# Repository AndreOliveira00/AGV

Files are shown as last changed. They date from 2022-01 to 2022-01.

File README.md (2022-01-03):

# AGV
 Automated Guided Vehicle Controlled by Atmega328P

Este repositório contém o relatório do projeto desenvolvido na Licenciatura de Engenharia Eletrotécnica e de Computadores na Unidade curricular LABSI. 
Imagens ilustrativas da PCB final e o desenvolvimento associado.

<b>OBJETIVOS DO PROJETO:</b>
<ul>
<li>Controlo do movimento do veículo, estabelecendo velocidade e sentido de rotação de 2 motores DC;</li>
<li>Processamento dos dados obtidos por um sensor de proximidade ultrassónico de forma a definir o movimento do carro;</li>
<li>Implementação do projeto segundo a orientação do microcontrolador ATMega328P;</li>
<li>Desenvolvimento de toda a programação C assim como desenho das PCB necessárias á execução do projeto;</li>
</ul>

Para outros esclarecimentos contacte pelo email 1181045@isep.ipp.pt.

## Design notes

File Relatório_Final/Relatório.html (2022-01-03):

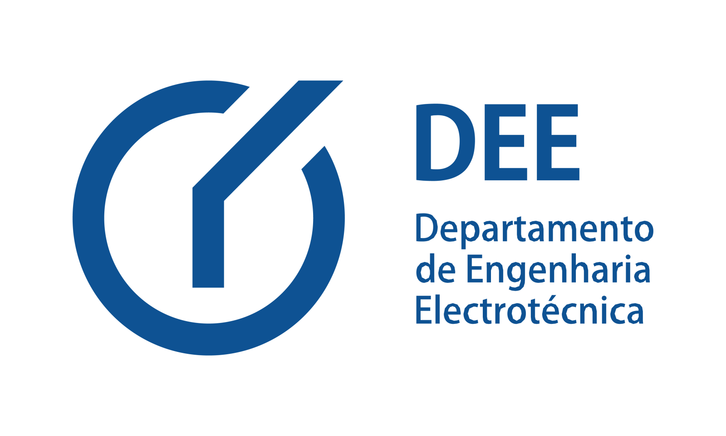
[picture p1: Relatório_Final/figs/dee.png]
| | Veículo autónomo - AGV | | | | | | |  LABSIS 2020/2021
Autores:
| André Oliveira (Nº 1181045) | | | | | 1181045@isep.ipp.pt
| Rodrigo Teixeira (Nº 1160843) | | | | | 1160843@isep.ipp.pt
Introdução | | | Arquitetura | Hardware | Software | | Resultados | Conclusões | | Referências
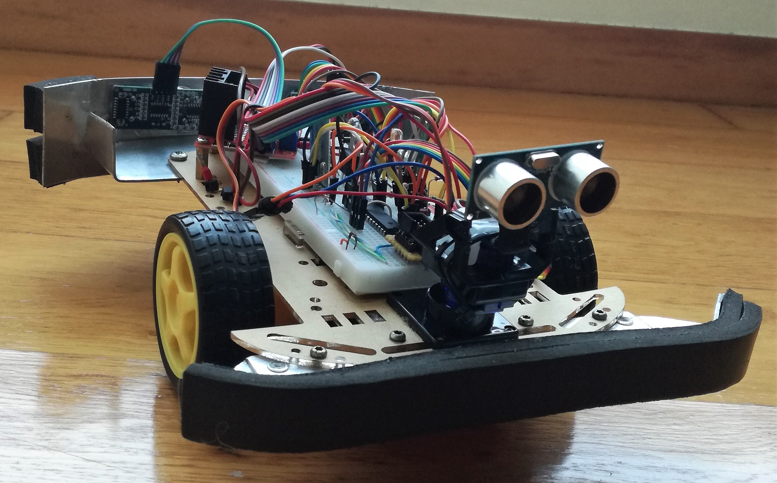
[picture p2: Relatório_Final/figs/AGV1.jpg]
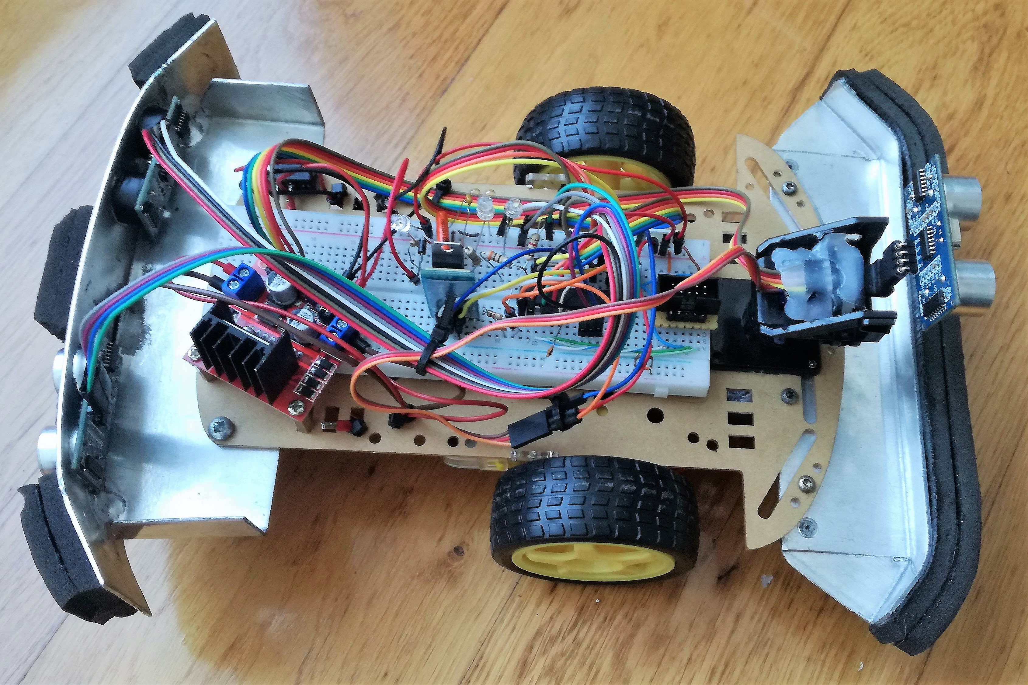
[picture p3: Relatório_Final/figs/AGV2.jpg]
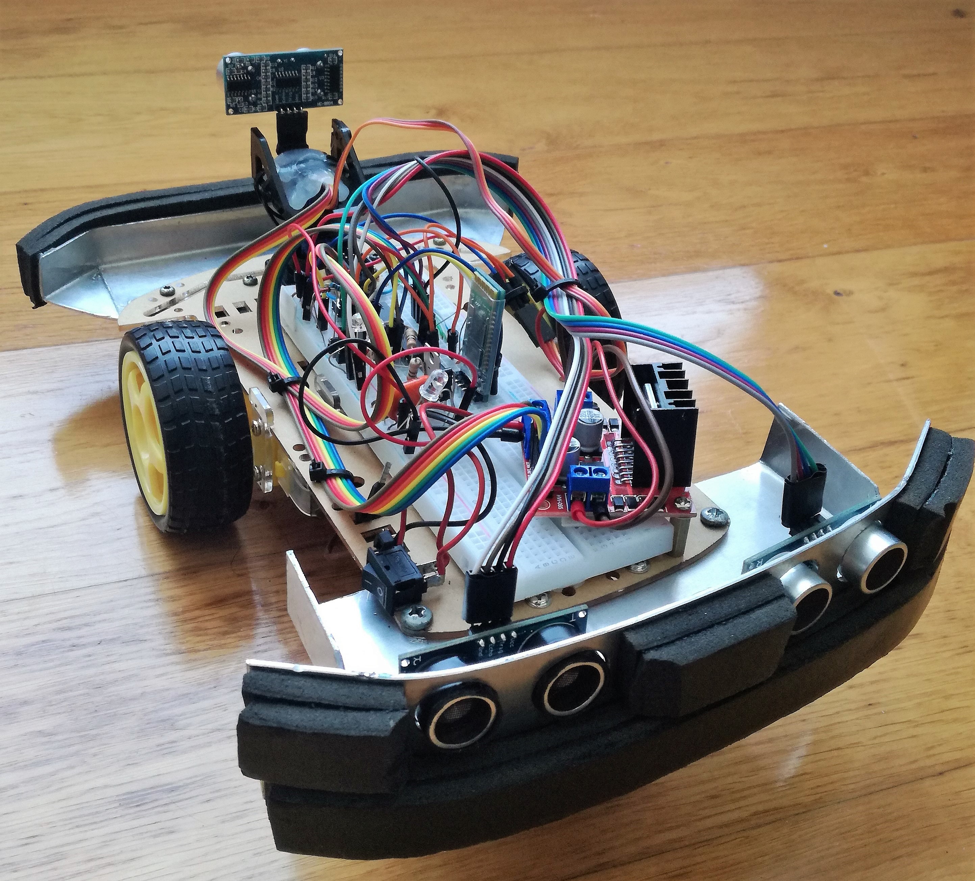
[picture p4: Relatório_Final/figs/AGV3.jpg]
  
Introdução | | | | | | | | | | | Início

No âmbito da Unidade Curricular Laboratório de Sistemas, foi proposta a conceção de um projeto com o respetivo protótipo funcional que recrutasse conhecimentos adquiridos ao longo do curso. Neste sentido, comprometemos-mos no desenvolvimento de um veículo autónomo, explorando posteriormente o seu controlo remotamente.
O presente relatório expõe os aspetos mais pertinentes que foram tidos em consideração durante o desenvolvimento do protótipo, destacando as principais dificuldades e realçando os conhecimentos adquiridos.

Objetivos

O compromisso para o desenvolvimento de um AGV passou pela estipulação das metas a serem atingidas. Com foco sempre na elaboração de um projeto eficaz e também económico foram enumerados os seguintes objetivos:

Controlo do movimento do veículo, estabelecendo velocidade e sentido de rotação de 2 motores DC;

Processamento dos dados obtidos por um sensor de proximidade ultrassónico de forma a definir o movimento do carro;

Implementação do projeto segundo a orientação do microcontrolador ATMega328P;

Desenvolvimento de toda a programação C assim como desenho das PCB necessárias á execução do projeto;

Modulação de um sistema económico e de carácter didático;

Estado da Arte

Com o desenvolvimento das tecnologias focadas no ramo de veículos autónomos e o aumento da capacidade computacional, foram nos apresentados os primeiros "robôs móveis" industriais. Esta conceção conjuga num só dispositivo de automação a capacidade de manipulação e manuseamento dos robôs e a mobilidade de um veículo autónomo. Neste campo destacam-se os AGV (Automatic Guided Vehicle), LGV (Laser Guided Vehicles), SGV (Self-Guided Vehicles) e AGC (Automated Guided Carts) com enorme potêncial no domínio industrial ou distribuição[1].

Um AGV é um veículo móvel autoguiado utilizado em ambientes que requerem transporte de produtos na produção e em armazéns. São programados com rotas definidas de recolha e entrega de materiais dentro de instalações de manufatura e de distribuição[2].

A sua flexibilidade permite a instalação em fábricas com reduzidas alterações na estrutura do shop floor. Geram um aumento da eficiência na produção dado redução dos recursos humanos necessários no desenvolvimento de trabalho repetitivo e permitindo uma cadência de ritmo de operação fixa. Os mesmos requerem pouca supervisão[3].

Alguns métodos de navegação como o Sistema Filoguiado consiste na definição do percurso do AGV por intermédio de condutores elétricos embutidos no chão. Estes condutores geram um campo magnético devido à corrente elétrica sinusoidal que por eles atravessam, seguidamente detetada por uma antena colocada no AGV conforme ilustrado na figura 1.(a) [4]. Um sistema pouco flexível e que implica a alteração do shop floor da fábrica[2].

Uma outra alternativa seria a substituição desse fio condutor por uma Fita Magnética ou Linhas Pintadas distintas na tonalidade relativamente ao resto do chão. A principal vantagem reside na flexibilidade com que se instala uma nova rota para o dispositivo conforme ilustrado na figura 1.(b)[4]. Porém o desgaste das fitas poderão interromper o trajeto do AGC (veículo apropriado)[2].

O sistema de Trilateração e Triangulação Laser apresenta-se como a forma de navegação mais segura que garante maior precisão do veículo através do mapeamento na memoria do mesmo. O AGV usa um sistema de lasers rotativos que permitem captar postes ou faróis refletores devidamente alocados conforme ilustrado na figura 1.(c) [4]. O resultado, o dispositivo não se perde sendo necessário detetar 3 destes faróis para ser capaz de obter a sua localização[2].

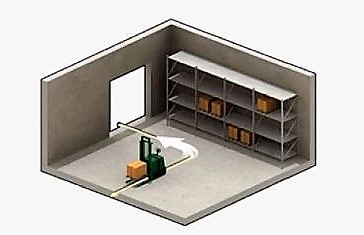
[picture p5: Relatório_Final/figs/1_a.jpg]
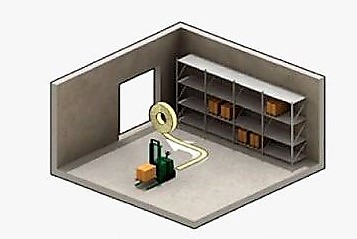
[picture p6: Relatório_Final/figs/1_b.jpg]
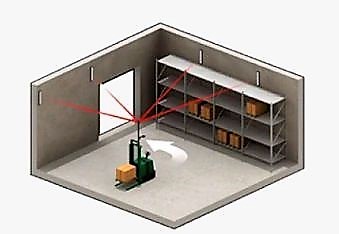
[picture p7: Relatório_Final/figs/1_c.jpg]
  

(a) Navegação por Sistema Filoguiado (b) Navegaço por uso de Fita Magnética/Pintada (c) Navegação por Sistema Triangulação Laser

Figura 1 - Métodos de Navegação

A orientação por GPS (Global positioning system) paralelamente com um sensor de bússola não apresentam resultados satisfatórios no interior de um edifício devido a bloqueios causados pelo mesmo, porém esta hipótese pode ver a ser desenvolvida com o auxílio de uma plataforma móvel, como um dispositivo Android, tendo apenas como pré requisitos a inclusão destes dois sensores[5]. O mesmo sistema seria benéfico na necessidade de transporte de mercadoria para um terreno de um hectare, sem constrições algumas, o sistema de GPS seria mais que suficiente dado a sua precisão rondar os 20 metros[6].

A implementação a partir de um sonar rotativo capaz de realizar um varrimento restrito de forma a obter um mapeamento dos obstáculos em frente do mesmo afasta-se um pouco da prática industrial, mas segue uma filosofia idêntica, automatização de um veículo. Para aplicações de pequena dimensão pode ser utilizado um servomotor capaz de controlar a rotação de 180° do sonar. Abordar este projeto com apenas um sonar implica um consumo de mais tempo no varrimento de todo o espaço por ele abrangido se quisermos manter alguma fiabilidade no sistema [7].

Uma implementação com recurso a 4 rodas teria uma estrutura idêntica à de um carro comum, ou seja, as rodas da frente teriam o controlo da direção e tração. Pretende-se apenas como requisito haver um sistema dotado destas características [2]. Relativamente à implementação com 2 rodas, esta pode ser encontrada em 2 versões comuns. Configuração diferencial, um eixo dianteiro com 2 motores de tração, sendo a direção controlada pelo sentido destas (a título de exemplo, uma movimentação para o lado direito requeria no motor esquerdo rotação da roda para a frente enquanto a direita faria o movimento contrário e vice-versa). Usual é também a configuração com 2 rodas de tração e direção, uma à frente e outra atrás com movimento de 360° , contendo duas rodas a meio, lado a lado, de apoio[2] , conforme ilustrado na figura 2.(a)[3].

Uma configuração unidirecional, composta por uma roda dianteira de tração e direção que roda sobre si própria. É chamado de controlo de tração triciclo visto incluir um eixo traseiro composto por duas rodas fixas, conforme ilustrado na figura 2.(b)[3]. Adicionalmente o controlo de direção também pode ser feito através de 3 (ou mais) rodas fixas na direção, desfasadas de 120° conforme ilustrado na figura 2.(c)[8]. Tem por desvantagem a necessidade um controlo mais complexo[3].

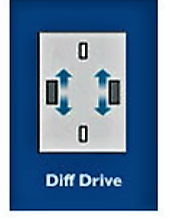
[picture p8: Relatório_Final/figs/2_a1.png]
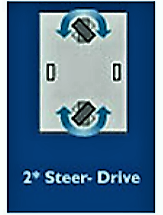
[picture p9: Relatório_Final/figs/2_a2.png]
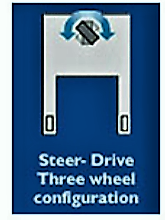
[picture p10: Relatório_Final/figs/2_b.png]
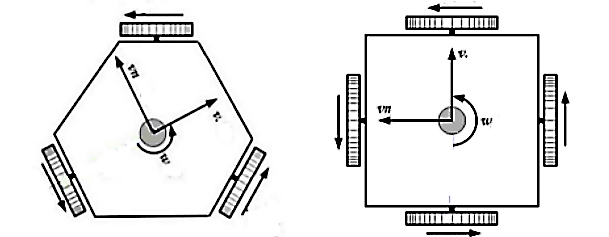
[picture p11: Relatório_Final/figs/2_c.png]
   

(a) Configurações diferenciais (b) Configuração unidirecional (c) Configurações omnidirecionais

Figura 2 - Configurações da locomoção dos AGV's

Sincronizado com o projeto e com o intuito de garantir a integridade do AGV no meio envolvente podemos equipá-lo com diversos equipamentos de segurança. A deteção de colisões através de sensores de obstáculos capaz de os detetarem calculando a distância entre este e o equipamento. Obstáculos mais baixos podem ser protegidos por uso de para-choques que quando acionados garantem a paragem instantânea do AGV. O uso de sinal de Áudio/Visual para alertar, por exemplo outros equipamentos ou mesmo trabalhadores da sua presença. Ou até segundo um controlo manual composto por botões de emergência que obrigam a paragem brusca do AGV.

A troca de informação entre AGV's sem a intervenção do humano proveniente do surgimento da IoT (Internet of Things) melhorou a monitorização do tráfego dos veículos. Estas comunicações podem ser realizadas com uso de transmissão rádio sendo necessário calcular o número de antenas necessárias bem como a sua colocação. Poderá ocorrer interferências criadas por sinais emitidos a pouca distância. Outra abordagem seria o uso da comunicação por infravermelhos tendo como desvantagem o facto de ser point to point, provocando interrupções do movimento do veículo aquando da transmissão de informação. Esta metodologia torna-se mais adequado para sistemas de baixa velocidade e menos ambiciosos. A comunicação por fio guia responsável por orientar o AGV evitando a ocorrência de "zonas mortas", uma das desvantagem da comunicação rádio. Na comunicação por circuitos de indução são criados circuitos dotados da criação de campo magnético à sua volta, responsáveis por transmitir comandos à antena dos AGV's e passada ao PLC (Programmable Logic Controller), que age em conformidade com o que lhe foi transmitido. Por último, a comunicação por Wi-Fi, sistema mais comum devido à sua flexibilidade e escalabilidade[9][2].

A forma como é realizada o carregamento do AGV pode definir a complexidade dos sistemas instalados assim como o número de equipamentos necessários. A troca manual que implica a imobilização do veículo entre 5 a 10 minutos. A automática recorrendo a uma estação própria para esse efeito. Carregamento de oportunidade, ou seja, utilizar o tempo de paragem do AGV para reabastecer as suas baterias. Carregamento automático, realiza as suas funções até determinada percentagem de energia. O carregamento fast charging, para carregamentos breves e frequentes das baterias. E o carregamento por indução, devido ao campo magnético gerado numa bobina que obriga a colocação de uma outra no veículo (a distâncias de 13 cm apresenta taxas de eficiência bastante elevadas, cerca de 97.4 %)[6].
Arquitetura | | | | | | | | | | | Início

Na figura 3, podemos observar a tradução das ideais estipuladas em algo físico. Ao diagrama de blocos do sistema mínimo, realizado anteriormente e presente também neste projeto, foi acrescentado os módulos necessários para a realização do mesmo.

Para a implementação de um AGV com os elementos mencionados necessitamos, principalmente de, mobilidade e autonomia. Estes dois fatores vão ser garantidos através da Ponte H L298N, à qual foram agregados dois motores DC, e pelas leituras efetuadas pelo Sonar HC-SR04 que por sua vez vai detetar obstáculos em várias direções com a ajuda de um Servo Motor SG90. Não abstante, são precias quatro baterias ICR18650, que na totalidade perfazem 14.8 V e 2200 mAh necessários para alimentar o veículo. Contudo, como o ATMega328P e a maioria dos módulos são alimentados apenas com 5 V contínuos, foi usado um Regulador de Tensão LM7805 que permite obter uma tensão de saída constante juntamente com um circuito de filtragem.

Adicionalmente, o grupo pensou que seria interessante o controlo remoto do AGV, para tal é necessário estabelecer comunicação entre o mesmo e uma aplicação de controlo, neste caso, via Bluetooth. Foi implementado um Módulo Bluetooth HC-05, com a finalidade mencionada anteriormente, a interface de controlo utilizada foi a aplicação Bluetooth Electronics. Com abertura para melhorias, foram adicionados mais dois Sonares HC-SR04 na parte traseira do veículo, de forma a evitar também qualquer objeto na marcha à retaguarda.

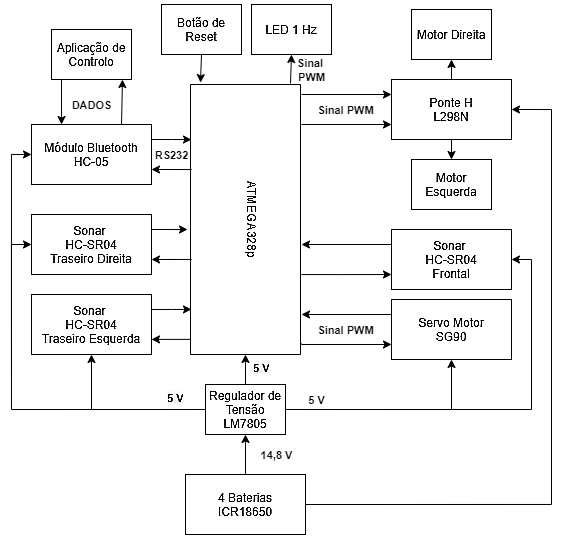
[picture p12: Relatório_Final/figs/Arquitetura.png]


Figura 3 - Arquitetura do AGV
Hardware | | | | | | | | | | | Início

ATMega328P

De modo a dar continuação ao projeto mínimo, sendo a implementação deste necessária neste trabalho, o grupo optou por usufruir do mesmo microcontrolador ATMega328P (https://datasheetspdf.com/pdf-file/1057332/ATMEL/ATmega328P/1). Este tipo de microcontroladores têm uma variante SMD ( Surface Mount ) e THT ( Through Hole Technology ), sendo a primeira variante de um tamanho muito mais reduzido e ideal para produção em grande escala, não sendo o caso, a tecnologia THT facilita a implementação, por exemplo, num PCB ou breadboard [10].

Este microcontrolador de 8 bits pode ser encontrado nas placas Arduino, sendo um dos mais populares do mercado. Dispõem de 28 pinos e tem 3 portas para uso, D, C e B. Para além do ATMega328P estava disponível o ATMega168, a principal diferença significativa entre os mesmo é a quantidade de memória programável, onde o escolhido apresenta o dobro[11]. O pinout do circuito pode ser visualizado na figura 4.

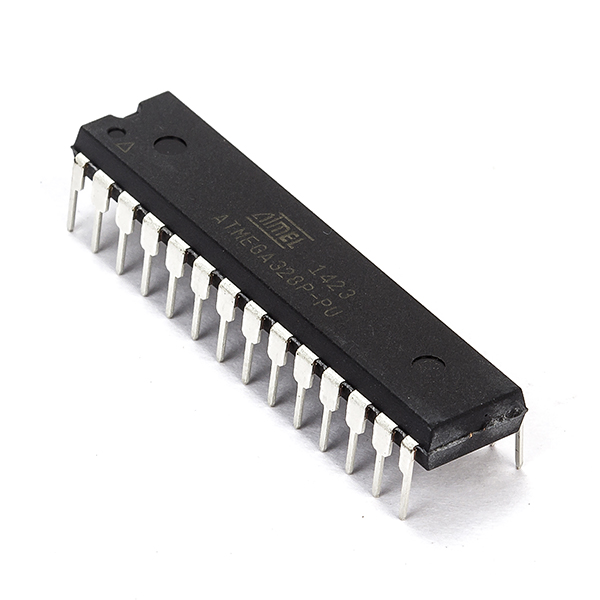
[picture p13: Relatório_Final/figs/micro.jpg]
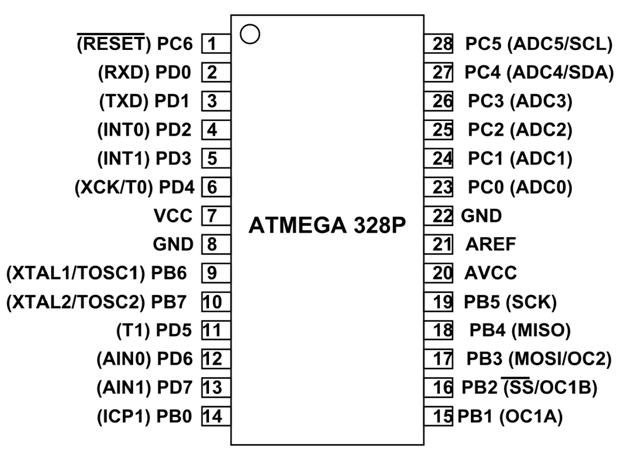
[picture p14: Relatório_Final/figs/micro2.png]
 

(a) ATMega328P (b) Pinout

Figura 4 - ATMega328P

Circuito de alimentação

a. Regulador de Tensão LM7805

O sistema de alimentação é uma das partes mais importantes do projeto, uma vez que sem este é impossível o correto funcionamento do AGV. Logo, visando também os movimentos autónomos do veículo a opção mais rentável seriam baterias, tendo em consideração também a portabilidade do mesmo. O regulador de tensão LM7805 (https://www.mouser.com/datasheet/2/149/LM7805-1010961.pdf) tem como principal função manter a tensão na sua saída constante. O circuito de regulação deve ser acompanhado de díodos e condensadores, criando assim um circuito de proteção contra eventuais descuidos e potenciais curto-circuitos[12].

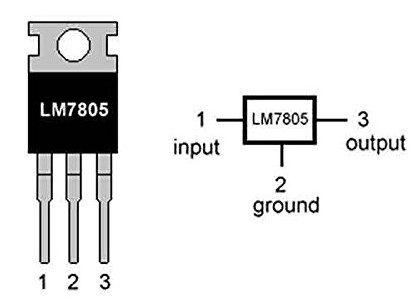
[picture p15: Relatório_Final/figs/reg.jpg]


Figura 5 - LM7805

A tensão de entrada pode variar entre os 7 V e 25 V, e a corrente máxima de 1 A ou 1,5 A, sendo o regulador selecionado de 1 A. É preciso ter em conta que este regulador pode libertar até 15 W de potência, sendo aconselhável o uso de um dissipador. O mesmo deve ser aplicado na traseira do regulador. De forma a proteger o veículo contra possíveis inversões de polaridade foi colocado um díodo diretamente polarizado na entrada, e para suavizar a tensão de saída e diminuir ruídos eletromagnéticos foram usados dois condensadores de desacoplamento, um na entrada de 0,33 µF e 0,1 µF na saída, reduzindo assim o efeito de ripple[13].

b. Baterias

As baterias de lítio ICR18650 de 3.7 V e 2200mAh são uma excelente escolha para este projeto, relativamente a baterias de outros materiais como níquel e chumbo, estas são mais leves e não sofrem do efeito de memória, características que são necessárias ter em mente ao dimensionar um AGV que visa a mobilidade.

As baterias selecionadas foram ligadas em série permitindo um acumular de 14.8 V e 2200 mAh quando devidamente carregadas. Dado a utilidade referida e a procura da reutilização de material, pudemos encontrá-las em baterias antigas de notebooks (com algum desgaste, mas estáveis o suficiente para efeito de desenvolvimento).

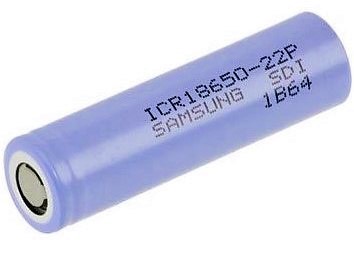
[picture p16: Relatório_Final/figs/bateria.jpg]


Figura 6 - Bateria ICR18650

Foram utilizadas 4 baterias ICR18650 sendo importante garantir que as baterias são todas do mesmo material, erros deste tipo podem levar ao mau desempenho do AGV ou até mesmo danificar-lo, podendo até se verificar sobreaquecimento ou fugas de corrente.

c. Circuito de proteção

Como mencionado anteriormente, o circuito de proteção permite evitar possíveis descuidos, como também eventuais curto-circuitos. Este detêm de dois díodos colocados em paralelo com a alimentação do microcontrolador, o Díodo Zener 5.1 V (https://www.jameco.com/Jameco/Products/ProdDS/36097VIS.pdf) atua como limitador de uma tensão teórica de 5.1V (limite de alimentação do ATMega328P de 5.5V) no caso de rutura do circuito de regulação.

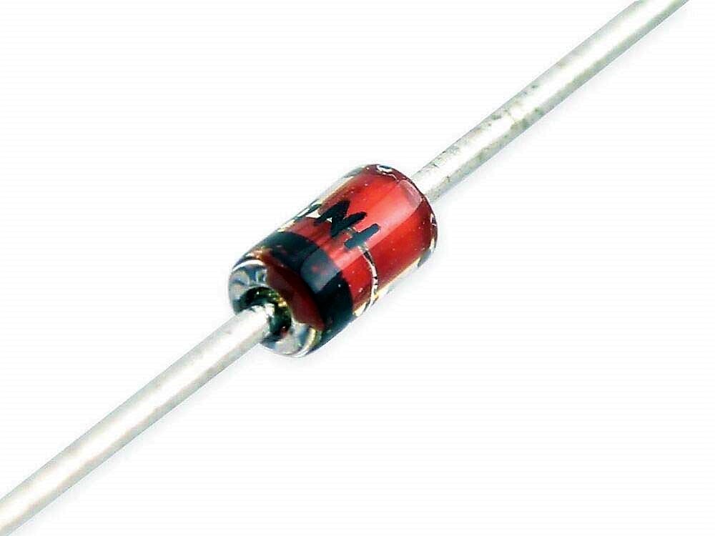
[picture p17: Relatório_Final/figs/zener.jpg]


Figura 7 - Díodo Zener 5.1 V

Paralelamente foi colocado um TVS (https://m.littelfuse.com/~/media/electronics/product_catalogs/littelfuse_tvs_diode_catalog.pdf.pdf) (Transiente Voltage Suppressor) e como o nome indica são utilizados em circuitos sensíveis onde ocorra uma repentina comutação de tensão num curto intervalo de tempo. Este componente é capaz de limitar a 9.2 V teóricos tensões de overshoot na passagem de 0 V para 5 V e dissipar esse excesso de potência na forma de calor.

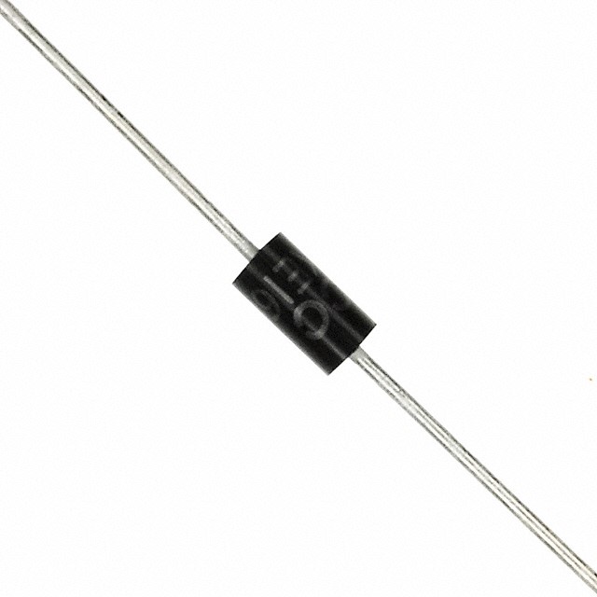
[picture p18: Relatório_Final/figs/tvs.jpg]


Figura 8 - TVS SMAJ5.0A

Módulo HC-05

No âmbito da comunicação entre aparelhos e transmissão de dados, o padrão global Bluetooth permite, em curtas distâncias e com baixo consumo de energia, uma ligação e tempo de resposta adequados para os AGV’s. Funciona através de limite de proximidade onde a comunicação é estabelecida através de frequência rádio aberta e permite transmissão como receção de dados sem necessitar de qualquer ligação física, sendo esta última abordagem extremamente adequada nestes projetos[14].

O módulo Bluetooth HC-05 (https://components101.com/sites/default/files/component_datasheet/HC-05%20Datasheet.pdf) permite implementar a ligação remota através de Serial Port Protocol seguindo o padrão RS232 entre este e o ATMega328P, podendo ser configurado como Master (consegue criar ligações com outros dispositivos) ou Slave (apenas consegue aceitar ligações criadas), sendo a segunda configuração implementada de origem pelo fabricante. Também existe o modo Loopback, fortemente utilizado para efeitos de teste, permite receber informações do Master e retorná-las seguidamente[15].

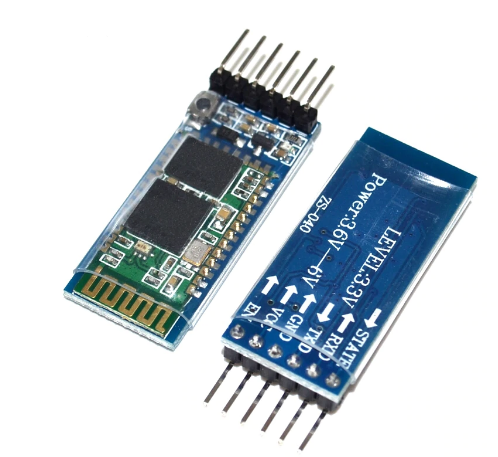
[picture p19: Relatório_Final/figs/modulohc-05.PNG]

Figura 9 - Módulo HC-05

Sonar HC-SR04

O sonar é de grande utilidade para um veículo autónomo. Composto por um transmissor e recetor, permite calcular a distância de a um determinado objeto. Transmite um impulso de som, chamado muitas vezes de ping, e após a emissão espera pela receção das reflexões/ecos do impulso criadas por eventuais obstáculos. É através deste modo que o recetor consegue calcular a distância após algum processamento de sinal[16].
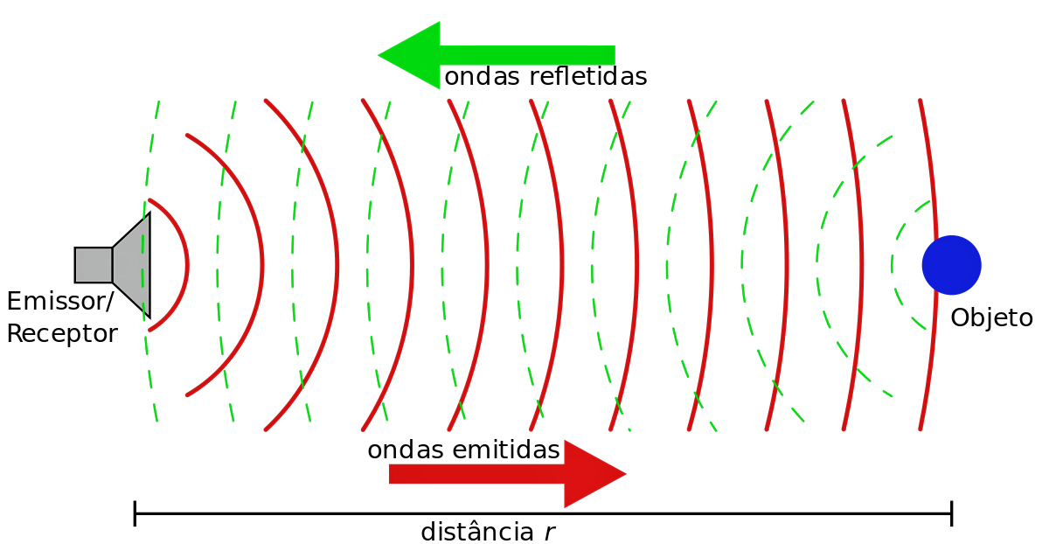
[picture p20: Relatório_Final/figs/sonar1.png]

Figura 10 - Funcionamento do Sonar

Existem variadíssimos sonares e imensos tipos de aplicação, no caso do AGV é de grande interesse ter o transmissor e recetor no mesmo local a realizar um movimento rotacional de forma a cobrir a maior área possível, pois permite ao veículo evitar obstáculos, e traçar melhor a sua rota. Este tipo de aplicação é designado de operação monoestática[17].

Um aspeto fulcral nos AGV’s é a sua mobilidade. Ou seja, têm de ser capazes de efetuar as manobras necessárias para se desviar de objetos, movendo-se por caminhos de difícil acesso ou evitar colisões com outros dispositivos idênticos. Para isto acontecer, a dimensão, peso e adaptabilidade do AGV são apenas alguns fatores a ter em consideração no momento de projeção deste tipo de projeto[16].

O sonar ultrasónico HC-SR04 permite atender às necessidades do projeto, tem capacidade de medir distâncias de 2 cm até 4 m com uma precisão de 4 mm. A velocidade do sinal emitida corresponde à velocidade do som (343 m/s), e também é uma opção ideal para microcontroladores devido à sua baixa corrente de operação (2mA) e alimentação de 5 V.
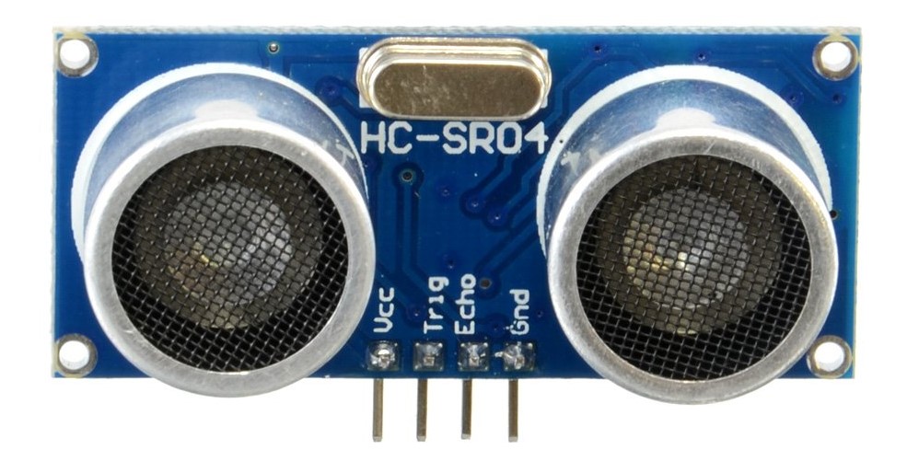
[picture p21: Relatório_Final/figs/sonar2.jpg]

Figura 11 - Sonar HC-SR04

Ponte H

A Ponte H é utilizada para controlar os motores DC em diversos campos da robótica, tais como locomoção de robôs, braços mecânicos e etc. Este tipo de circuito é de extrema importância ao trabalhar com microcontroladores, isto porque, os motores DC são cargas indutivas que requerem normalmente correntes superiores às que o microcontrolador consegue fornecer.

Posto isto, ao ligar diretamente o motor a uma das suas saídas poderíamos danificar o mesmo. Este problema poderia ser solucionado com um transístor, porém, não seria possível inverter a polaridade do motor[18]. Visando assim o tópico da adaptabilidade do AGV, a Ponte H acaba por ser uma elegante solução para este problema, pois é capaz de inverter a polaridade dos motores e também de regularas suas velocidades atrás da aplicação de um sinal PWM nos pinos de controlo[18].
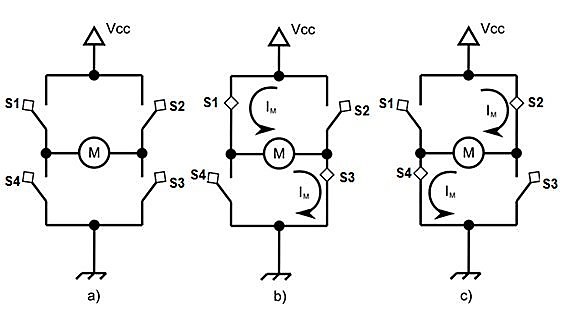
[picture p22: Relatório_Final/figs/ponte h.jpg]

(a) Desligado (b) Sentido Normal (c) Sentido Contrário

Figura 12 - Ponte H

Para melhor dimensionamento do AGV, é necessário manter os tópicos abordados anteriormente em mente, portanto tornar os circuitos o mais compacto possível é uma obrigação. O circuito integrado L298N ocupa menor espaço e é de baixa complexidade, para além disso permite o controle de dois motores. Para além destas vantagens, o mesmo responde a sinais PWN, tornando assim possível regular as tensões de saída e desta forma regular a velocidade dos motores[19].

Figura 13 - Módulo Ponte H com CI L298N

Para usufruir do sinal PWN e movimentar o AGV com velocidade regulável são usados dois Motores TT de 3 a 6 V com duas rodas acopladas. De dimensões reduzidas estes são uma aposta perfeita para pequenos projetos como este, atingem uma velocidade de 200 +/- 10 % rpm sem carga com uma corrente a rondar os 160 mA e alimentados a 6 V DC. Já com 3 V DC, sem carga acoplada, podemos contar com um débido te corrente de cerca de 150 mA e uma velocidade de 90 +/- 10 % rmp [20].
Já que a tensão de referência ronda os 14.8 V, via software decidimos limitar a 6 V DC aos motores. Esta ação é possível limitando o valor de OCR0A e OCR0B, no caso, uma variável global que define a velocidade aplicada em ambos. Considerando a tensão a aplicar aos motores varia linearmente com o duty cycle da onda PWM gerada pelo TIMER0, podemos conseguir o referido limitando a um valor de 103. Ou seja, (103/255) * 14.8 = 5.978 V.

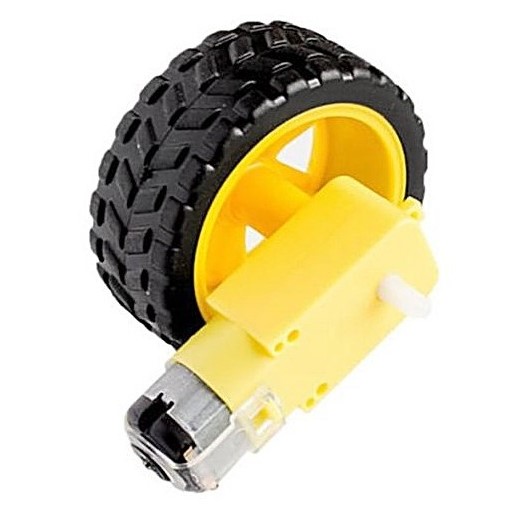
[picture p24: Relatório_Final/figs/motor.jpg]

Figura 14 - Motor DC com roda

Para além dos dois motores que efetuam o deslocamento do AGV é utilizado um terceiro, um servo motor SG90. Este é responsável pela rotação do sonar frontal sendo capaz de rodar 60º em 0.12 segundos[21]. Infelizmente o mesmo não foi verificado durante o projeto, pelo que foi necessário definir um “delay mecânico” durante a rotação do sonar de forma a não criar distúrbios maiores nas leituras realizadas pelo mesmo.

Conta com uma tensão operacional de 5 V e um consumo de 220 mA. Alimentado a 4.8 V regista um torque de 1.2 kg sem qualquer carga, suficiente para deslocar o sonar. Opera a uma frequência de 50 Hz, pelo que o PWM que o controla deve ter um período de 20 ms dos quais um duty cycle a 5 % (On-Time 1 ms) coloca o servo motor a -90 graus e um duty cycle a 10 % (On-Time 2 ms) coloca o servo motor a +90 graus, segundo as considerações feitas na Tabela 3 [21].


Figura 15 - Servo SG90

Roda livre giratória

A roda proveniente do kit adquirido para montar a estrutura do AGV apresenta algum atrito quando este pretende seguir em frente tendo previamente iniciado uma rotação. Esta oposição ao movimento condiciona a qualidade de deslocamento do veículo. Para correção do sucedido o grupo optou por adquirir uma roda que apresentasse melhor comportamento. A roda selecionada encontra-se na figura 16. De frisar que esta roda ainda podia ser substituída por uma roda livre esférica, não sendo necessário o sistema deslocar-se conforme o movimento.



Figura 16 - Roda livre giratória adotada

Para-choques

Seguindo as estruturas existentes no mercado relativamente a AGV’s industriais e de forma a garantir a integridade deste no meio envolvente foi desenvolvido dois para-choques com capacidade de aguentar embates em objetos segundo a altura do chassi e na parte de trás de forma a segurar os dois sonares. A estrutura é feita de alumínio pesando cerca de 250 g o que corresponde a um acréscimo de 45.5 % da massa original do AGV e 31.3 % da massa total. As proteções são rebitadas nas laterais e dobradas permitindo uma maior abrangência do veículo na altura do embate.

Programador

O programador USBASP (https://eecs.oregonstate.edu/education/docs/ece375/USBASP-UG.pdf) (USB AVR Serial Programmer) com conexão USB integrada permitiu realizar comunicação série entre o microcontrolador e o computador sendo apenas necessário estabelecer as devidas ligações e configurações a esse efeito, pudendo então enviar o ficheiro .hex, portador do código desenvolvido para controlo do AGV.

Constituído por uma ATMega8 ou ATMega88 com clock fornecido por um cristal de 12 MHz entre outros componentes simples permite a leitura e escrita na EEPROM do microcontrolador, firmware, fuse bits e lock bits contante com uma velocidade de programação superior a 5 kBytes/segundo[22]. Na fig 17 pode ser observar o programador descrito. Junto desta temos a leitura dos fuse bits cujo o seu significado pode ser encontrado no início do capítulo Software.

 

Figura 17 - Programador USBASP Figura 18 - Programador AVRDUDESS

Esquema Elétrico

O sofware utilizado para criar o esquema do projeto foi o EAGLE, apesar de termos verificado posteriormente uma maior simplicidade na realização deste em KiCad. O software EAGLE destacou-se devido à facilidade no momento de criar a PCB, nomeadamente devido à ferramenta Autorouter. Em comparação com outros sofwares do mesmo género, este é usado para um ambiente mais profissional e para eventual fabrico de PCB's em larga escala. A versatalidade do mesmo permitiu que não fosse necessária qualquer tipo de biblioteca externa para além da criada pelo grupo para os motores DC.

Podemos afirmar que, o esquema elétrico é nada mais do que a arquitetura do projeto mas com a blueprint e ligações dos componentes mais detalhadas entre si. Na fig 19, podemos ver quais os pinos do microcontrolador utilizados por cada componente, por exemplo, podemos verificar que o sonar frontal é composto por quatro pinos (VCC, TRIGGER, ECHO e GND) e estão conectados, respectivamente, à alimentação de 5 V, PD4 do microcontrolador, PD2 do microcontrolador e GND.

Adicionou-se dois leds capazes de sinalizar o utilizador se a alimentação ao circuito foi devidamente colocada. Desta forma, um led verde acende caso esta alimentação seja válida. Caso contrário, podemos observar um led vermelho a acender e verificar a ação do díodo de proteção que suportará com toda esta tensão inversamente aplicada.



Figura 19 - Esquema Elétrico do projeto

PCB

A PCB foi dimensionada com o mesmo software, a versatilidade do EAGLE já foi mencionada anteriormente, e a possibilidade de enviar o esquema elétrico para a PCB com as ligações físicas entre componentes é novamente prova disso. As dimensões e características dos componentes são estabelecidas previamente através das bibliotecas existentes, neste caso todos eles são THT portanto a placa terá perfurações proporcionais às dimensões dos componentes exigida.

Como podemos verificar na figura 20, existem três cores predominantes: vermelho, azul e verde. Respetivamente corresponde à parte superior, parte inferior e orifícios para a solda dos componentes. As áreas a vermelho e azul correspondem a zonas de massa no respetivo plano. A ferramenta vias do desenho de PCBs em EAGLE permite fazer a união das área de massa do plano superior com o inferior. Elementos como os três sonares, o servo motor, as ligações à Ponte H e motores serão conectadas ao devido componente com o auxílio de alguns cabos para o exterior dado a sua fixação na placa em questão ser impossível, devido à mobilidade requerida por cada um.



Figura 20 - PCB do projeto

Custo Total do Projeto

Tabela 1 - Lista de material necessário para o protótipo.



De frisar que o valor apresentado corresponde ao preço atual do mercado. No entanto, nem todo o material foi comprado. O regulador LM7805, os condensadores, as resistências, o díodo 1N4007 e o zener de 5,1 V foram fornecidos pelo DEE do ISEP. As baterias são provenientes de uma bateria de um computador portátil danificado, pelo que o sistema de restabelecimento da carga é o original do notebook. Já o para-choques foi dimensionado, rebitado, limado e adaptado à estrutura do AGV por nós mesmos, sendo o material por ele constituído de baixa massa, trazendo pouca perturbação no funcionamento do projeto. Desta forma foi possível uma redução significativa de custos no valor final do protótipo apresentado.
Software | | | | | | | | | | | Início

O desenvolvimento de todo o código foi realizado em linguagem C no ambiente de desenvolvimento Atmel Studio 7 conforme requerido, onde se torna notório a simplicidade na programação do ATMega328P frente à linguagem Assembly.

Antes de iniciar a programação foi necessário averiguar qual seria a configuração dos fuse bits, responsáveis por definir a velocidade e tensão pela qual o microcontrolador irá operar. Tratam-se de 3 bytes de memória não volátil que podem ser reconfigurados sempre que necessário. A sua leitura pode ser feita usando o software AVRDUDESS que também permite a configuração destes mesmos bytes. Auxiliarmente usou-se a calculadora online Engbedded Atmel AVR® Fuse Calculator (https://www.engbedded.com/fusecalc/) paralelamente com as informações prestadas pelo datasheet (https://datasheetspdf.com/pdf-file/1057332/ATMEL/ATmega328P/1) do microcontrolador.

Verificou-se que o ATMega328P operava a 1 MHz por defeito a partir de circuito oscilador RC interno com Fuse Low Byte a 0x62, Fuse High Byte a 0xD9, Extended Action a 0xFF e LockBit a 0xFF. Os resultados podem ser validados na figura 18.

Para o desenvolvimento do código capaz de instruir instruções a serem efetuadas pelo AVR em questão foi necessário recorrer a um conjunto de bibliotecas. Segue uma breve descrição das mesmas.

<avr/io.h> - Permite a utilização dos I/O do microcontrolador e contém os nomes da maioria dos seus registos.

<avr/interrupt.h> - Permite a utilização das interrupções do microcontrolador com maior comodidade através dos macros que esta estabelece, como por exemplo ativar/desativar globalmente as interrupções (bit I do SREG).

<util/delay.h> - Permite o estabelecimento de um atraso propositado, como por exemplo a necessidade de um intervalo de espera enquanto o servo motor finaliza uma rotação (delay mecânico). Aconselha-se o estabelecimento da frequência a que o microcontrolador está a operar segundo o define (#define F_CPU 1000000UL).

Com o intuito de tornar o código mais legível foram estabelecidos vários defines devidamente interpretados pelo compilador. Segue uma breve descrição dos mesmos.

#define _500ms 244 - Valor que permite de certa forma aumentar intervalo de tempo estabelecido para a comutação do estado do LED (que opera a 1 Hz) durante a interrupção de overflow do TIMER0.

#define pwm(val) 255*val/100 - Expressão responsável por converter o valor introduzido em "val" (duty cicle) percentual para uma base binária (0 a 255).

#define dist_minf 50 - Distância mínima estabelecida para a zona de perigo do sonar da frente.

#define dist_mint 30 - Distância mínima estabelecida para a zona de perigo do sonar de trás.

#define ON 1 - Indica modo automático ativo.

#define OFF 0 - Indica modo controlado ativo.

CONFIGURAÇÕES DE REGISTOS

As configurações iniciais dos registos do microcontrolador permitem uma correta utilização dos periféricos deste além de estabeleceram o devido funcionamento das propriedades pelas quais este é constituído.

Deste modo, foram utilizadas duas interrupções externas (para a leitura do estado do pino ECHO de dois módulos ultrassónicos) onde a deteção do flanco ascendente ou descendente é conseguida dado a alteração cíclica do registo EICRA a cada passagem pela rotina de interrupção e pela função responsável por ativar a operação dos sonares.

Relativamente aos timers, procurou-se a otimização utilizando o TIMER0 em modo Fast PWM com ambas as saídas OC0A e OC0B (output compare) ativas responsável por gerar uma interrupção de overflow a cada 2.048 ms passados, o que corresponde a uma frequência de 500 Hz, consideração essencial no momento de aplicação do sinal PWM no controlo dos motores, evitando a ocorrência de solavancos no seu funcionamento. O tempo de interrupção auxiliado com o estabelecimento da constante _500ms permitiu a alteração do estado o LED de 500 em 500 ms. Adicionalmente foi possível obter dois sinais PWM para fins de controlo da velocidade de rotação dos motores, conforme anteriormente explicado, alterando o valor dos registos OCR0A e OCR0B. Seguem-se os cálculos necessários.

$$Tempo = {{(Prescaler \times 256) \over F_{Clock}} = {8 \times 256 \over 1 \times 10^6 } = 2.048 \space ms}$$
Equação 1

Já o TIMER1 foi também configurado em modo Fast PWM, mas apenas com OC1A ativo para fins de controlo da posição do servo motor. A utilização deste timer de 16 bits no modo 14 permitiu gerar uma onda quadrada com frequência de 50 Hz necessária para o correto funcionamento do servo motor. Só neste modo foi possível obter tão elevada precisão. A onda quadrada foi conseguida fixando o valor 19999 no registo ICR1. A variação do duty cycle da onda foi possível através do registo OCR1A. Seguem-se os cálculos necessários.

$$f_{PWM} = {{F_{Clock} \over Prescaler(1+TOP)} = {1 \times 10^6 \over 1(1+19999)} = 50 \space Hz}$$
Equação 2

Por fim, o TIMER2 também configurado em modo Fast PWM, responsável por gerar uma interrupção por overflow a cada 16.384 ms. Este timer configurado neste modo possui o tempo suficiente para fazer o cálculo da distância dos sonares traseiros sem ser necessário a implementação de um contador por software como observado no TIMER0, conforme será explicado à frente. Seguem-se os cálculos necessários.

$$Tempo = {{(Prescaler \times 256) \over F_{Clock}} = {64 \times 256 \over 1 \times 10^6 } = 16.384 \space ms}$$
Equação 3

Relativamente às configurações da USART para estabelecer uma comunicação wireless Bluetooth com recurso ao módulo HC-05 foi alocado o valor 12 no registo UBRR0, conforme o recomendado no datasheet do ATMega328P a uma frequência de 1 MHz para um baud rate de 9600 bps a operar ao dobro da velocidade. Foi também ativada a interrupção de receção da USART e permitida uma receção e transmissão de informação.

As restantes configurações podem ser consultadas na tabela 2 com a devida justificação relativamente à sua implementação.

Tabela 2 - Configuração dos periféricos.



FUNÇÃO MAIN

De forma a expor a solução implementada para atingir os objetivos estipulados segue-se análise baseada em fluxogramas e, caso seja necessário, a apresentação de alguns trechos de código.

Na função Main são feitas as inicializações executando a função void init() e colocando o servo motor na posição central (0°). Antes de entrar no ciclo infinito é enviada uma mensagem ao utilizador "AGV READY......". Neste momento é possível ao utilizador interagir com o AGV através do botão ON/OFF presente na interface da aplicação utilizada - Bluetooth Electronics - figura 22. Botão ON inicia o modo controlado, caso contrário inica o modo automático.

O módulo automático executa as instruções recebidas da última comunicação série USART. Conforme é possível observar, a interface com o utilizador é constituída por um terminal que apresentas as mensagens envias e recebidas. Ainda abaixo, uma caixa de texto onde podemos enviar mensagens personalizadas. O controlo no canto inferior direito permite deslocar o AGV nas oito direções apresentadas. Por fim, no canto inferior esquerdo, uma barra deslizante capaz de controlar a velocidade do veículo (estava velocidade encontra-se limitada a 6 V via software, correspondente a 104 numa escala de 0 a 255 para uma tensão de alimentação máxima de 14.8 V).

Na ocorrência do AGV operar em modo automático é verificado se o mesmo se encontra numa fase rotatória provocada pela deteção de um obstáculo. Neste cenário o sonar é colocado na posição central e o protótipo encontra-se a rodar (direita ou esquerda) seguido de uma série de leituras da distância frontal a qualquer objeto. Quando esta distância for maior que 80 cm (distância de segurança da frente) o AGV para de rodar e potencialmente inicia a progressão em frente. Se este cenário não for verificado é feita uma deteção do estado do veículo.

O estado 0 indica que o carro está a deslocar-se em frente e a fazer um varrimento constante numa amplitude de -20° a +20° do espaço à sua frente (esta pequena rotação permite a deteção de obstáculos com fornas irregulares, não paralelas ao sonar). A deteção de um obstáculo faz com que o AGV se desloque para trás durante um segundo ou um dos sonares traseiros detetarem um obstáculo a menos de 30 cm (distância que define a zona de perigo). É alterado o estado do AGV para 1 e guardada a posição do servo motor no momento da deteção do objeto para futura reposição desta.

Neste momento o veículo encontra-se parado e em condições de executar a condição de estado 1. O servo motor coloca o sonar virado para a esquerda e aguarda a sua estabilização. Por fim faz a leitura da distância lida pelo sonar nesta posição para futura comparação.

É então iniciado o estado 2, pelo que o servo motor coloca o sonar virado para a direita. Após as mesmas restrições de espera necessárias à rotação do sonar é, feita a leitura da distância lida pelo mesmo e comparada com o valor anteriormente guardado. Na situação destas serem iguais o AGV opta por rodar para a direita. É então reposta a posição do servo motor, redefinido o estado a 0 e iniciada a rotação do veículo. O ciclo é repetido atéque ocorra uma mudança do modo de operação de automático para controlado.



Figura 21 - Fluxograma da função Main



Figura 22 - Aplicação Bluetooth Electronics

Ao longo do seu funcionamento o servo motor é responsável por coloca o sonar em cinco posições diferentes. Imaginando uma semicircunferência em que conseguimos definir uma rotação de -90° a +90° e sendo a sua orientação central alocada a 0° podemos estabelecer a tabela 3.

Tabela 3 - Posições possíveis do servo.



ROTINA DE INTERRUPÇÃO DE OVERFLOW DO TIMER0

O sistema implementado procura a otimização de recursos, desta forma foi desenvolvido um algoritmo que permita alocar a responsabilidade de controlo da velocidade de rotação dos motores, comutação do estado do LED sinalizador de sistema ativo à frequência de 1 Hz e contagem dos tempos necessários às leituras do sonar frontal. O modo implementado permite entrar na rotina de overflow presente no fluxograma da figura 23 a cada 2.048 ms, processando-se os seguintes acontecimentos:

Controlo do LED sinalizador de sistema ativo - Operação responsável por comutar o estado do LED a cada 500 ms. é realizado um decremento da variável cont_timer iniciada com o valor do define _500ms. Assim que este contador alcançar o valor zero, este é reiniciado e é alterado o estado do LED.

Incremento do contador associado ao módulo ultrassónico frontal - Na ocorrência deste módulo se encontrar em espera pelo fim do impulso de ECHO por ele gerado, esta condição fica responsável por contar o número de overflows ocorridos que seguidamente serão processados noutra função.

Controlo da velocidade de rotação dos motores - Segunda as configurações deste timer e tendo as saídas OC0A e OC0B ativas é possível alterar o duty cycle das ondas quadradas responsáveis por controlar a velocidade de rotação de cada motor alterando apenas o valor de registo OCR0A e OCR0B ao longo do código.



Figura 23 - Fluxograma da rotina de interrupção do TIMER0

ROTINAS DE INTERRUPÇÕES EXTERNAS

A fim de contabilizar o tempo decorrido desde a deteção do estado alto do sinal ECHO após o envio do impulso sonoro por parte de um dos três sonares foram utilizadas as duas interrupções externas contidas no ATMega328P. Estas seguem um raciocínio idêntico, no entanto optamos pelo uso da interrupção externa zero em sincronia com o TIMER0 para a contagem de tempo do sonar frontal e a interrupção externa um em sincronia com o TIMER2 para a contagem de tempo dos sonares traseiros.

Ambas as interrupções são iniciadas com a deteção de uma subida de flanco no respetivo pino sendo seguidamente configurado o EICRA para que a próxima interrupção seja gerada por um flanco descendente.

Relativamente à interrupção externa zero, a deteção de uma subida de flanco origina a leitura do valor do TCNT0 (Timer/Counter Register 0) e inicialização das flags necessárias. Já na interrupção externa um há também uma inicialização de flags sendo que o TIMER2 é ligado e reiniciado.

Segue-se a deteção da próxima ocorrência, flanco descendente do sinal ECHO. Relativamente à interrupção externa zero, é feita uma nova leitura do valor do TCNT0 seguido dos cálculos associados para a obtenção da distância medida e desbloqueado o valor da flag a 0 indicando a obtenção de uma nova distância frontal. A solução implementada para esta interrupção necessita de apenas de uma flag de 2 bits (flag = 0 indica obtenção de nova distância, flag = 1 indica que vai entrar a primeira vez na interrupção, flag = 2 indica que vai entrar a segunda vez na interrupção e está pronta a calcular a nova distância). No entanto, para a interrupção externa um é utilizada duas flags de 1 bit (f_t = 1 indica primeira vez na interrupção e f_t = 0 indica segunda vez na interrupção) e flag_t (flag_t = 0 aguarda processamento de nova distância e flag_t = 1 indica obtenção de nova distância). Assim é ativada a 1 a flag_t e feito o cálculo da nova distância traseira.

Com o intuito de apresentar o raciocínio acima explicado deixamos um trecho de código da rotina de interrupção INT0, idêntica à rotina INT1 alterando apenas as configurações do registo EICRA, flags utilizadas e cálculo, que de certa forma se torna mais simples, sendo apenas necessário dividir o tempo (em µs) decorrido entre alteração do estado dos flancos do sinal ECHO por 58 para a obtenção de uma distância em cm.



Na figura 24 é apresentado o fluxograma ilustrativo desta parte onde podemos observar de forma simplificada o algoritmo implementado relativo às interrupções externas zero e um.



Figura 24 - Fluxograma das rotinas de interrupção externa INT0 e INT1

FUNÇÃO DE DISPARO DO MÓDULO ULTRASSÓNICO

Para os disparos dos módulos ultrassónicos foi implementada a função void triggersonar(), idêntica para os 3 sonares, responsável por colocar a 1 o pino onde está ligado o TRIGGER do respetivo módulo ultrassónico durante um período de pelo menos 10 µs repondo depois o seu valor nulo. A vantagem de operar com o microcontrolador segundo uma frequência interna de 1 MHz é o facto de cada ciclo de clock levar cerca de 1 µs. Com o auxílio da ferramenta Processor Status do ambiente de desenvolvimento Atmel Studio 7, durante a simulação foi possível verificar que decorrem cerca de 11 µs fruto dos 6 comandos seguidos à ativação do TRIGGER do sonar. Considerando como exemplo o sonar frontal, o disparo deste fará atuar uma interrupção externa devido à ocorrência de um sinal com flanco positivo (INT0 conforme explicado anteriormente) a qual será responsável por obter uma nova distância lida. O processo termina quando a flag for 0 outra vez.

Seguindo o raciocínio que foi feito para as rotinas de interrupções externas, apresentamos um excerto de código ilustrativo da explicação acima enunciado com o respetivo fluxograma presente na figura 25.





Figura 25 - Fluxograma para as funções dos módulos ultrassónicos

ROTINA DE INTERRUPÇÃO DA USART

Uma última interrupção é gerada sempre que ocorra uma receção correta de informação por parte da USART. A ativação da flag RXC0 do registo UCSR0A informa-nos do sucedido. A informação pode ser lida do registo UDR0 neste momento. Igualmente pode ser envia informação de forma a obter algum feedback no momento da programação do AGV escrevendo o pretendido neste mesmo registo somente quando a flag UDRE0 estiver a 1.

As mensagens enviadas correspondem a um char (8 bits) conforme apresentado na secção das configurações. Este valor é armazenado, portanto na variável data. A receção de um 'A' corresponde à ativação do botão do canto superior esquerdo da interface apresentada na figura 22 e origina o modo de controlo via Bluetooth. Contrariamente a receção de um 'B' corresponde à colocação no estado OFF desse mesmo botão significando a ativação do modo automático por parte do AGV. De outra forma, a receção de um 'W' indica a vontade de alterar a velocidade do veículo, sendo seguida de dois a quatro bytes, os primeiros bytes (dois na situação da velocidade a aplicar apenas conter um algarismo, três bytes se a velocidade conter dois algarismos e quatro bytes caso contenha três algarismos) são devidamente processados terminando a trama com um 'Y'. Um exemplo desta trama pode ser visto dentro da caixa de texto da figura 22.

As restantes letras recebidas indicam a vontade de mudança de direção proveniente do utilizador. Assim que o controlador é solto, é enviado um 'S' colocando o AGV em posição de STOP. A informação é enviada do dispositivo Android para o módulo HC-05 sempre que ocorrem mudanças de valor da mesma. A alocação de um estado de 0 a 8 na variável dir deverá ser devidamente processado posteriormente na main.

Na figura 26 é apresentado o fluxograma ilustrativo desta parte onde podemos observar de forma simplificada o algoritmo implementado relativo à interrupção da receção de informação da USART.



Figura 26 - Fluxograma da rotina de interrupçõo da USART

FUNÇÃO DE ROTAÇÃO DA POSIÇÃO DO SONAR FRONTAL

A função void rotar_sonar() é responsável por processar a posição em que servo motor coloca o sonar e deslocá-la para a seguinte, ou seja, considerando o sistema apresentado na tabela 2, o servo motor deve rodar segundo a seguinte ordem - 20° → 0° → + 20° → 0° → - 20° e por aí adiante. Na função main (estado = 0) é verificado se o sonar se encontra em rotação e feito uma espera até que este sistema estabilize para fazer as devidas leituras da distância frontal pretendida.

Na figura 27 é apresentado o fluxograma ilustrativo desta parte onde podemos observar de forma simplificada o algoritmo implementado relativo à função de rotação da posição do sonar frontal.



Figura 27 - Fluxograma da função de rotação da posição do sonar frontal
Resultados | | | | | | | | | | | Início
O produto final obtido deste trabalho pode ser observado no vídeo editado com recurso ao software DaVinci Resolve (https://www.blackmagicdesign.com/pt/products/davinciresolve/). Para a sua visualização basta clicar em cima deste. No vídeo é possível analisar os dois modos de operação assim como a interface adaptada ao projeto segundo a aplicação Bluetooth Electronics.
Conclusões | | | | | | | | | | | Início

O estudo realizado segundo o software e hardware apresentado deixa claro a possibilidade de implementação de um veículo autónomo capaz de se desviar de objetos e selecionar um caminho adequado a seguir.

Para projeto final, verificamos um AGV muito responsivo e capaz de interagir com o utilizador via comunicação Bluetooth, uma funcionalidade essencial no momento de realização de debug no código.

O que começou por ser um projeto orientado à redução de custos e procura de eficácia revelou-se um pouco mais dispendioso. No entanto, seguindo a análise feita no custo total de hardware e dada a reutilização de alguns materiais como o alumínio e as baterias foi possível poupar 44.54 euros face ao valor apresentado.

Principais dificuldades

Com vista à melhoria da orientação do veículo recorreu-se a uma roda livre giratória diferente. O problema foi atenuado, mas não solucionado. Desta forma, fornecendo um valor superior de duty cycle à roda esquerda foi possível equilibrar minimamente o deslocamento do mesmo.

A leitura individual dos sonares era realizada com sucesso e elevada exatidão, no entanto, a combinação do sonar frontal e traseiro esquerdo com o sonar traseiro direito revelou uma pequena perturbação para o sistema, não respondendo inicialmente conforme pedido. Com a realização de vários testes e adaptação de software foi possível corrigir o sistema para que realizasse o pretendido.

Optamos por adotar a frequência de oscilação padrão, sabendo na mesma que esta pode ocorrer em erros superior a 10%. Caso fosse necessária maior precisão no projeto abordado, os fuse bits poderiam ser facilmente alterados [23] sendo apenas necessário adicionar um circuito oscilador externo constituído por um cristal da frequência em questão e 2 condensadores de cerâmica no intervalo de 12 a 22 pF (consultar datasheet).

Relativamente à estrutura, tivemos cuidado na distribuição devida do peso, dado que um valor baixo desta variável permite reduzir a inércia e aumentar a facilidade de manobra do veículo. Os módulos de 4 pilhas ICR18650 foram alocados junto ao eixo das duas rodas e os componentes na parte superior devidamente espaçados. O peso do alumínio igualmente distribuído e anexado ao chassi do veículo aumentando a robustez do mesmo no caso de falha do sistema de deteção de obstáculos.

Pontos fortes

O varrimento do sonar frontal numa amplitude de 40 graus permitem uma maior adaptabilidade ao meio no qual este circula.

As interrupções utilizadas permitem a poupança de tempo na execução das instruções, evitando overload no programa principal e, portanto, uma carga adicional do microprocessador.

O sistema de alimentação responsivo constituído por diversos componentes de proteção é capaz de indicar ao utilizador a correta polarização da alimentação e proteger o microcontrolador de tensões de overshoot na passagem de 0 V para 5 V, dissipando esse excesso de potência na forma de calor.

Controlo da velocidade estipulada pelo utilizador, limitando que esta corresponda a uma tensão contínua superior a 6 V para os motores.

Potenciais melhorias

A limitação de recursos fornecidos pelo microcontrolador impediu-nos de implementar um display capaz de transmitir informação adicional, como sentido selecionado quando tem de escolher uma nova direção ou um amostrador dinâmico capaz de preencher o ecrã à medida que se aproxima de um obstáculo.

Controlo da velocidade instantânea de cada motor, processamento e correção desta com vista na utilização de um encoder rotativo dado a existência de um disco perfurado que acompanha o eixo de cada roda.

Aumentar a frequência de leitura dos sonares traseiros, fracionado ainda mais o tempo durante a deslocação para trás.

Controlar o ângulo de rotação do sonar dianteiro recorrendo a dois sensores nas suas laterais, permitindo assim uma maior eficiência na realização dos “delays mecânicos” conforme mencionado.

Implementação de um sensor de colisão, idêntico aos veículos pessoais e após processamento desta informação, parar o AGV se necessário.

Teste de outros sonares presentes no mercado, como o SRF05 ou US-015 já que estes apresentam maior precisão nas leituras.

Considerações finais

O projeto foi uma oportunidade desenvolver e implementar algumas capacidades de pesquisa e conhecimentos adquiridos ao longo da LEEC desde o cumprimento do cronograma estipulado ao resultado final.
Referências | | | | | | | | | | | Início

[1] R. P. Rocha, "Estado da Arte da Robótica Móvel em Portugal," pp. 1-21, 2001.

[2] P. M. S. T. de Castro, P. P. Camanho, L. F. M. da Silva, and P. M. G. P. Moreira, "IDMEC - Faculdade de Engenharia da Universidade do Porto," Int. J. Struct. Integr., vol. 1, no. 2, pp. 161-172, 2010.

[3] T. F. Cordeiro, "SISTEMA DE DETEÇÃO E CONTORNO DE OBSTÁCULOS PARA ROBÓTICA MÓVEL BASEADO EM SENSOR KINECT," 2014.

[4] Y. J. Lee, "Effective use of android sensors based on visualization of sensor information," Int. J. Multimed. Ubiquitous Eng., vol. 10, no. 9, pp. 299-308, Sep. 2015.

[5] C. J. Snyman and T. I. Van Niekerk, "Development of a Navigation System for an Autonomous Guided Vehicle using Android Technology," vol. 4, no. 6, pp. 3027-3033, 2013.

[6] "Implementação de AGV's - Um estudo de caso industrial." 2018.

[7] W.-C. Chiang, C. Ramamurthy, T. N. Mundhenk, and E. L. Hall, "Range Detection for AGV Using a Rotating Sonar Sensor."

[8] K. Roy, "Modelagem e Controle de um Veículo Omnidirecional," Lead. Edge, vol. 31, pp. 1182-1191, 2012.

[9] J. M. De, F. Costa, P. Doutora, M. Da, G. Vieira, and B. Almeida, "INSTITUTO SUPERIOR DE ENGENHARIA DE LISBOA Automatização de sistema de separação de peças com recurso a um tapete rolante e um robot e processamento de imagem."

[10] W. Preston, “The difference between THT and SMT | Harwin,” Harwin.com, 2018. [Online]. Available: https://www.harwin.com/the-difference-between-tht-and-smt/. [Accessed: 09-Jan-2021].

[11] Atmel, “ATmega328/P [Datasheet],” AVR Microcontrollers, 2016. [Online]. Available: https://datasheetspdf.com/pdf-file/1057332/ATMEL/ATmega328P/1.

[12] “LM78XX/LM78XXA 3-Terminal 1A Positive Voltage Regulator Features,” 2008.

[13] N. Dias, “Eletrónica Geral Laboratório de Sistemas,” 2015.

[14] “Como usar o Arduino Bluetooth HC-05 em modo mestre - FilipeFlop.” [Online]. Available: https://www.filipeflop.com/blog/tutorial-arduino-bluetooth-hc-05-mestre/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. [Accessed: 10-Nov-2020].

[15] “Configuração Master-Slave do HC-05 com Arduino | Curto Circuito.” [Online]. Available: https://www.curtocircuito.com.br/blog/arduino-e-hc-05:-configuracao-master-slave. [Accessed: 10-Nov-2020].

[16] LastMinuteEngineers, “How HC-SR04 Ultrasonic Sensor Works & Interface It With Arduino,” www.lastminuteengineers.com. [Online]. Available: https://lastminuteengineers.com/arduino-sr04-ultrasonic-sensor-tutorial/. [Accessed: 10-Nov-2020].

[17] “Sonar – Wikipédia, a enciclopédia livre.” [Online]. Available: https://pt.wikipedia.org/wiki/Sonar?fbclid=IwAR2oGFK6cbJUHsShFcwBzdZl9FYklx2-EQ3CKFshNqBr3UduXSTbd_28Xmg. [Accessed: 10-Nov-2020].

[18] F. dos Reis, “Como funciona uma Ponte H – Controle direcional de motores DC,” 2017. [Online]. Available: http://www.bosontreinamentos.com.br/eletronica/curso-de-eletronica/como-funciona-uma-ponte-h-controle-direcional-de-motores-dc/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. [Accessed: 10-Nov-2020].

[19] “Motores CC com L298N Dual H-Bridge e Arduino | Oficina DroneBot.” [Online]. Available: https://dronebotworkshop.com/dc-motors-l298n-h-bridge/. [Accessed: 10-Nov-2020].

[20] I. Kecerdasan and P. Ikep, “DC Gearbox Motor - ‘TT Motor,’”.

[21] “Servo Motor SG-90 Basics, Pinout, Wire Description, Datasheet,” Components101, 2017. [Online]. Available: https://components101.com/servo-motor-basics-pinout-datasheet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. [Accessed: 11-Jan-2021].

[22] “Building and installing USBASP-USB programmer of AVR microcontrollers - Do It Easy With ScienceProg.” [Online]. Available: https://scienceprog.com/building-and-installing-usbasp-usb-programmer-of-avr-microcontrollers/. [Accessed: 07-Jan-2021].

[23] “Learn About ATmega328P Fuse Bits and How to Use Them with an External Crystal Oscillator.” [Online]. Available: https://www.allaboutcircuits.com/projects/atmega328p-fuse-bits-and-an-external-crystal-oscillator/. [Accessed: 25-Oct-2020].
| | | | | | | | | | | Início

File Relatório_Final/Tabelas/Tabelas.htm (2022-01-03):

Hardware | Quantidade | Preço (€)
Microcontrolador ATmega328P | 1 | 3,69
Motores, L298, sonar, estrutura, servomotor e suporte, botão ON/OFF, leds e rodas | 1 | 17,0
Roda livre metálica | 1 | 1,99
Sonar HC-SR04 | 2 | 5,00
Módulo Bluetooth HC-05 | 1 | 8,24
Regulador LM7805 | 1 | 0,49
Condensadores | 3 | 0,46
Resistências | 6 | 1,01
Para-choques | 2 | 20,0
Baterias ICR18650 | 4 | 14,0
Programador | 1 | 8,50
Zener 5,1 V | 1 | 0,62
TVS SMAJ5.0A | 1 | 0,36
Díodo 1N4007 | 1 | 0,06
Total | - | 81,42

De frisar que o valor apresentado corresponde ao preço atual do mercado. No entanto, nem todo o material foi comprado. O regulador LM7805, os condensadores, as resistências e o díodo de 5,1 V foram fornecidos pelo DEE do ISEP. As baterias são provenientes de uma bateria de um computador portátil danificado, pelo que o sistema de restabelecimento da carga é o original do notebook. Já o para-choques foi dimensionado, rebitado, limado e adaptado à estrutura do AGV por nós mesmos, sendo o material por ele constituído de baixa massa, trazendo pouca perturbação no funcionamento deste mesmo. Desta forma foi possível uma redução significativa de custos no valor final do projeto apresentado.

Programador

Conclusão

cronograma

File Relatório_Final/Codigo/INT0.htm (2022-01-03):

ISR(INT0_vect){ // Interrupção externa 0

if(flag == 1){ // flag = 1, primeira vez na interrupção

tempinit = TCNT0; // 1 tcnt0 = 8 us

cont = 0; // Reset nº de overflows

flag = 2; // flag = 2, segunda vez na interrupção

EICRA &= (~(1 << ISC00)); // Altera registo para detetar um flanco descendente do sonar frontal

}

else { // Segunda vez na interrupção

tempfim = TCNT0; // Leitura do tempo final

tempo=(8*(((cont-1)*256)+(255-tempinit)+tempfim)); // Tempo em us

dist = (tempo/58); // Conversão em cm considerando a velocidade do som = 343 ms/s a 20ºC

flag = 0; // flag = 0, indica obtenção de um novo valor de distância

EICRA|= (1<<ISC01) | (1<<ISC00); // Altera registo para detetar um flanco ascendente do sonar frontal

}

}

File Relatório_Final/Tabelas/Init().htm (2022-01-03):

DDRD = 0b11110010; PORTD = 0b00000000; | Definir PD7 (saída IN3), PD6 e PD5 como saída (OC0A=ENA (motor esquerdo) e OC0B=ENB (motor direito) respetivamente), PD4 (Trig saída sonar frente), PD3 (INT1, Pino Eco sonar trás esquerdo – entrada), PD2 (INT0, Pino Eco sonar frente- entrada) PD1 (RX0) Desativa os pull-up do PORTD
DDRB = 0b00110111; PORTB = 0b11001000; | Definir pino 0,1,2,4 e 5 do PORTB como saída (LED 1Hz, PWM, IN2, IN4 e IN1 respetivamente) Ligar pull-ups nas entradas não utilizadas
DDRC = 0b00000011; PORTC = 0b11111100; | Definir PC0 (Trig saída sonar trás esquerdo), PC1 (Trig saída sonar trás direito), PC2 (Pino Eco sonar trás direito- entrada) Ligar pull-ups nas entradas não utilizadas
TIMER0 Modo Fast PWM para controlo dos Motores, LED 1 Hz e leitura de tempos do sonar frontal, gera interrupção a cada 2,048 ms passados
TCCR0A |= (1<<COM0A1) | (1<<COM0B1) | (1<<WGM01) | (1<<WGM00); TCCR0B |= (1<<CS01); TIMSK0 |= (1<<TOIE0); | | OC0A, OC0B ligado (clear OC0x on Compare Match - non-inverting mode) Prescaler = 8 Ativar a interrupt para Timer/Counter0, Overflow Interrupt Enable
TIMER1 Modo 14 Fast PWM para controlo da posição do servo motor
TCCR1A |= (1<<COM1A1) | (1<<WGM11); TCCR1B |= (1<<WGM12) | (1<<WGM13) | (1<<CS10); ICR1 =19999; OCR1A =1850; | | OC1A ligado (clear OC0x on Compare Match - non-inverting mode) Prescaler = 1 f = 50 Hz Servo motor na posição central (0 graus)
TIMER2 Modo Fast PWM para leitura de tempos do sonar traseiro esquerdo e direito, gera interrupção a cada 16,384 ms passados
TCCR2A |= (1<<WGM21) | (1<<WGM20); TCCR2B |= (1<<CS22); | | Estabelecimento de TOP=0xFF Prescaler = 64
USART
UBRR0 = 12; UCSR0A = (1<<U2X0); UCSR0B = (1<<RXEN0) | (1<<TXEN0) | (1 << RXCIE0); UCSR0C = (1<<UCSZ01) |(1<<UCSZ00); | | Definição de baud rate a 9600 Dobro da velocidade Ativação da receção, transmissão e interrupção da receção de informação da USART Transmissão a 8 bits (tamanho de cada carácter), 1 stop bit e comunicação assíncrona
INTERRUPÇÕES EXTERNAS
EIMSK |= (1<<INT0) | (1<<INT1); EICRA |= (1<<ISC00) | (1<<ISC01) | (1<<ISC10) | (1<<ISC11); | | Ativar as interrupções externas 0 e 1 Subida do sinal gera interrupção (INT0 e INT1)
sei(); | | Ativar interrupções globais

VALOR DO REGISTO OCR1A | GRAUS | ORIENTAÇÃO
2800 | -90º | Esquerda
2100 | -20º | Orientado à esquerda
1850 | 0º | Centro
1600 | +20º | Orientado à direita
800 | +90º | Direita

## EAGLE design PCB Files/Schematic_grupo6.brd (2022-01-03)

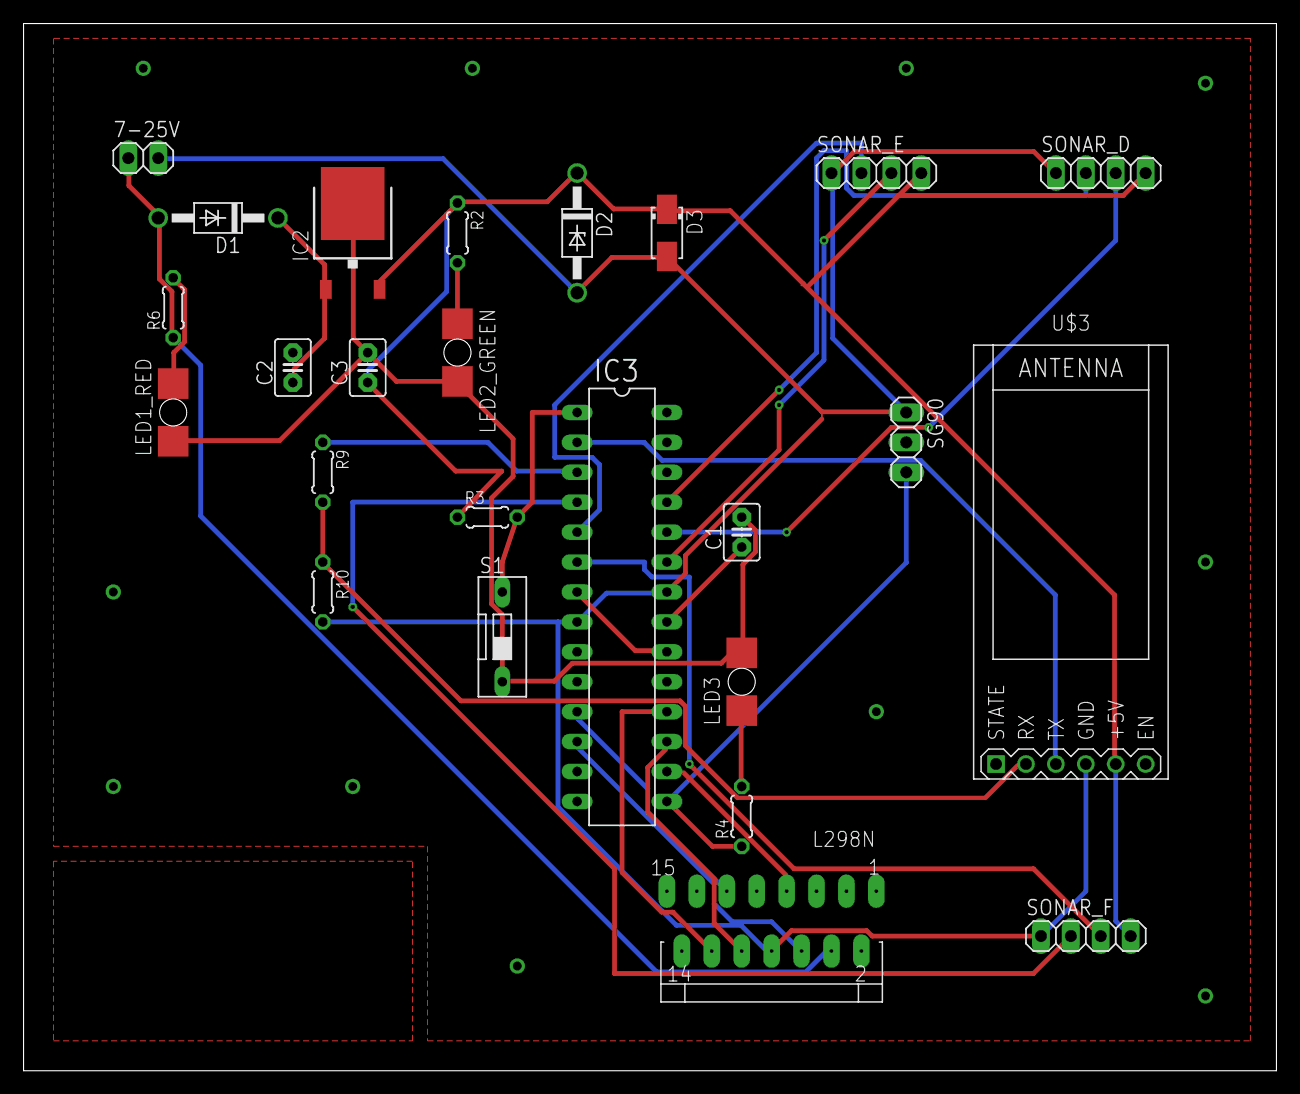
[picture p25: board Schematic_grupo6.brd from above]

Board: 2 copper layers, 106.3 x 88.9 mm, 25 parts (0 on the bottom side), 26 nets.

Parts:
7-25V: 1X02
C1: 22pF; C2.5-3
C2: 330nF; C2.5-3
C3: 100nF; C2.5-3
D1: 1N4007; DO41-10
D2: 1N4728; DO41Z10
D3: SMAJ5.0A; DO214AC
IC2: LM 7805; TO252
IC3: ATMEGA328P; DIL28-3
L298N: MW-15
LED1_RED, LED2_GREEN, LED3: LAP4-BOTTOM; P47F-BOTTOM
R2, R4: 300; 0204/5
R3: 10k; 0204/5
R6: 2.2k; 0204/5
R9: 1k; 0204/5
R10: 2k; 0204/5
S1: DS-01
SG90: 1X03
SONAR_D: 1X04
SONAR_E: 1X04
SONAR_F: 1X04
U$3: WIRELESS-BLUETOOTH-HC-05

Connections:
0: C1.2, C3.2, IC2.3, LED1_RED.A, LED2_GREEN.C, LED3.C, S1.1
7-25V: 7-25V.1, D1.A, L298N.4, R6.1
.: C3.1, D2.C, D3.C, IC2.2, R2.1, R3.1, SONAR_D.4, SONAR_E.4, SONAR_F.4, U$3.5
AREF: C1.1, IC3.21
AVCC: IC3.7, IC3.20
GND: 7-25V.2, D2.A, D3.A, IC3.8, IC3.22, L298N.8, R10.2, SG90.1, SONAR_D.1, SONAR_E.1, SONAR_F.1, U$3.4
unnamed: LED3.A, R4.2
unnamed: LED1_RED.C, R6.2
unnamed: C2.1, D1.C, IC2.1
unnamed: LED2_GREEN.A, R2.2
PB1: IC3.15, R4.1, SG90.3
PB2: IC3.16, L298N.7
PB3: IC3.17, L298N.10
PC0: IC3.23, SONAR_E.3
PC1: IC3.24, SONAR_D.3
PC2: IC3.25, SONAR_D.2
PD0: IC3.2, U$3.3
PD1: IC3.3, R9.1
PD1': R9.2, R10.1, U$3.2
PD2: IC3.4, SONAR_F.2
PD3: IC3.5, SONAR_E.2
PD4: IC3.6, SONAR_F.3
PD5: IC3.11, L298N.11
PD6: IC3.12, L298N.6
RESET: IC3.1, R3.2, S1.2
S$1: IC3.18, L298N.12

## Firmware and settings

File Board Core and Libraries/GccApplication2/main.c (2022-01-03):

/*
 * VEÍCULO AUTÓNOMO
 *
 * Created: 16/01/2021 21:23:32
 * Author : André
 */ 

// BIBLIOTECAS
#include <avr/io.h>
#include <avr/interrupt.h>
#include <util/delay.h> 
//#include <string.h> 

// CONSTANTES
#define F_CPU 1000000UL
#define _500ms		244								//	Valor para contar 500ms 244
#define pwm(val)	255*val/100						//	% Duty Cicle - fazer pwm(dutycicle)		
//#define pc2_on  0b00000100						//  Sonar sem interrupt (direito)
#define dist_minf 50								//  Distancia minima sonar da frente
#define dist_mint 30								//  Distancia minima sonar da frente
#define ON 1										//  Modo automático ativo
#define OFF 0										//  Modo controlado ativo

// VARIAVEIS
volatile unsigned int cont_timer = _500ms, tempo=0, dist_m=0, dist=0, dist_e=0, dist_d=0, COUNTA[10],pulse;		// 2 bytes (65536)
volatile unsigned char dir=0, velesq=pwm(1),vel_aux=0, reset_velo=0, aut=ON, cnt_10us=0,f_t=0,k=0, flag=0, flag_t=0, f_avirar=0, flag_servo=0, cont=0, cont_10us=0, tempinit=0, tempfim=0, direcao=0, flag_tras=0;	// vel = velocidade controlada
char  data= ' ', vel=pwm(20), velo[6]="000", msg[20]; 
/*
* cont_timer	-> Contador auxiliar para ciclo de 500 ms
* tempo			-> Tempo da leitura do sonar frontal
* dist			-> Distância registada pelo sonar frontal
* dist_e		-> Distância registada pelo sonar frontal quando servo está virado à esquerda
* dist_d		-> Distância registada pelo sonar frontal quando servo está virado à direita
* pulse			-> Tempo da leitura do sonar traseiro direito
* dir			-> Direção do AGV
* velesq		-> Velocidade extra para compensação do deifeito do motor esquerdo
* vel_aux		-> Velocidade auxiliar na ocorrencia de falha de conversão da velocidade emitida pelo utilizador
* reset_velo	-> Flag que verifica se o vetor velo[6] e as flgas associadas já foram resetadas
* aut			-> Flag que indica o estado automático ou controlado do AGV
* f_t			-> Flag que controla o acesso à interrupção 1
* k				-> Contador para conversão da velocidade emitida pelo utilizador
* flag			-> Flag que controla a correta determinação da distância do sonar frontal
* flag_t		-> Flag que controla a correta determinação da distância dos sonar traseiro esquerdo
* flag_tras		-> Flag que indica que os sonares traseiros já detetaram um obtáculo e não pode recuar mais
* f_avirar		-> Flag que indica que o AGV está numa fase de rotação,ou seja, a determinar a melhor direção para seguir em frente
* flag_servo	-> Flag que indica que o servomotor está numa fase de rotação de 20 graus
* cont			-> Contador auxiliar responsável por indicar o numero de overflows do timer 0 para efeitos de determinação do tempo gerado pelo sinal do sonar frontal
* cont_10us		-> Flag para efeito gasto de cicos do CPU de forma a passaram pelo menos 10 us (operação usada nos sonares)
* tempinit		-> Tempo inicial do timer 0 no incio da determinação do tempo gerado pelo sinal do sonar frontal
* tempfim		-> Tempo final do timer 0 no fim da determinação do tempo gerado pelo sinal do sonar frontal
* direcao		-> Establece o estado de operação do AGV
* data			-> Char retornada da comunicação Bluetooth
* vel			-> Velocidade controlada do AGV
* velo[6]		-> Vetor usado para auxilio da conversão da string recebida pela comunicação Bluetooth num inteiro lógico
* msg[20]		-> String a condicionar ao longo do programa para enviar para o terminal na aplicação
*/
// PROTOTIPOS DE FUNÇÕES
void init(void);
void motores(void);
void frente(void);
void tras(void);
void direita(void);
void esquerda(void);
void frentedireita(void);
void frenteesquerda(void);
void trasdireita(void);
void trasesquerda(void); 
void stop(void);
float mode(int a[],int n);
void send_msg(char *buffer);
unsigned char USART_ReceivePolling();
void teste_traseiro(void);
void send_dist();
void scan_e(void);
void scan_d(void);

void init(void)
{
	DDRD  = 0b11110010;			// Definir PD6 e PD5 como saída	(OC0A=ENA(motorA) e OC0B=ENB(motorB) respetivamente) PD4(Trig saída frente) PD2(Eco entrada) PD7 (saída IN3) PD2 (INT0) PD3 (INT1) PD1(RX0)
 	PORTD = 0b00000000;			// Inicializar OC0A e OC0B
	
	DDRB  = 0b00110111;			// Definir pino 0,1,2,4 e 5 do PORTB como saída	(LED 1Hz, PWM, IN2, IN4 e IN1 respetivamente)
	PORTB = 0b11001000;			// Inicializar OC0A e ligar pull-ups nas entradas não utilizadas
	
	DDRC  = 0b00000011;			// 2 Sonares atrás PC0 e PC1(Trig saída) PC2(Eco entrada)
	PORTC = 0b11111100;
	
	// TIMER0 para os Motores e Led
	// Modo Fast PWM
	TCCR0A |= (1 << COM0A1) | (1 << COM0B1) | (1 << WGM01) | (1 << WGM00);		// Modo fast PWM ativo, com OC0A, OC0B ligado (clear OC0x on Compare Match - non-inverting mode)
	TCCR0B |= (0 << WGM02) | (0 << CS02) | (1 << CS01) | (0 << CS00);			// PSC 8
	// T = (PSC * 256) / 1X10E6
	// T = (8 * 256) / 1X10E6 = 2.048 ms
	// 244 * 2.048e-3 = 499.712 ms
	TIMSK0 |= (1 << TOIE0);		// Ativar a interrupt para  Timer/Counter0, Overflow Interrupt Enable
	
	// TIMER1
	TCCR1A|=(1<<COM1A1) | (1<<WGM11);				// Modo Fast PWM (14) ativo, com OC1A ligado (clear OC0x on Compare Match - non-inverting mode)
	TCCR1B|=(1<<WGM12) | (1<<WGM13) | (1<<CS10);	// PSC 1
	ICR1=19999;										// f = 50 Hz
	OCR1A=1850;										// Servo posição 0 graus
	
	//TIMER2
	//TCCR2A|= (1<<COM2A1) | (1<<WGM21) | (1<<WGM20); //Fast PWM com TOP=0xFF
	TCCR2A|= (1<<WGM21) | (1<<WGM20);			//Fast PWM com TOP=0xFF
	TCCR2B|= (1<<CS22) ; //prescaler 64		prescaler 32 = (1<<CS21) | (1<<CS20)
	// T = (PSC * 256) / 1X10E6
	// T = (64 * 256) / 1X10E6 = 16.384 ms		//Suficiente para fazer a contagem do tempo do sonar 4 metros / 343 metros/s = 11.66 ms
	
	// USART
	UBRR0 = 12;													// Set baud rate
	UCSR0A = (1<<U2X0);											// Dobro da velocidade
	UCSR0B = (1<<RXEN0)|(1<<TXEN0)|(1 << RXCIE0);				// Enable receiver and transmitter
	UCSR0C = (0<<USBS0)|(0<<UPM01)|(1<<UCSZ01)|(1<<UCSZ00);		// Set frame format: 8data, 1stop bit
	
	// EXTERNAL INTERRUPTS
	EIMSK |= (1<<INT0) | (1<<INT1); // Ativar as interrupções externas 0 e 1
	EICRA |= (1<<ISC00) | (1<<ISC10); // Any logical change on INT0 and INT1 generates an interrupt request.
	EICRA &= (~(1<<ISC01));
	EICRA &= (~(1<<ISC11));
	//EICRA |= (1<<ISC00) | (1<<ISC10) | (1<<ISC11); 				// Subida do sinal gera interrupção (INT0)

	sei();						// Ativar interrupções globais
}

ISR (TIMER0_OVF_vect)
{
	cont++;
	cont_timer --;
	if(cont_timer == 0)
	{
		PORTB ^= 0b00000001;	//XOR (Se igual 0, se diferente 1), ou seja, se desligado (0) passa a estar ligado
		cont_timer = _500ms;
	}
}

ISR(INT0_vect){				// Interrupção externa
	if(flag == 1){			// flag = 1, primeira vez na interrupção
		tempinit = TCNT0;	// 1 tcnt0 = 8 us
		cont = 0;			// Reset nº de overflows
		flag = 2;
		//EICRA &= (~(1 << ISC00));
	}
	//if(flag == 2){		//flag = 2, segunda vez na interrupção
	else{
		tempfim = TCNT0;
		tempo=(8*(((cont-1)*256)+(255-tempinit)+tempfim));	//us
		//dist_m = (tempo/58);  // Em cm
		dist = (tempo/58);		// Em cm
		flag = 0;				// Obtive valor novo de dist
	}
}

ISR(INT1_vect)
{
	if (f_t==1)					// Segunda vez
	{
		TCCR2B=0;				// Desliga o timer2
		pulse=TCNT2;			// 1 tcnt2 = 0.064ms
		flag_t=1;
		TCNT2=0;
		f_t=0;
	}
	if (f_t==0)					// Primeira vez
	{
		//EICRA &= (~(1 << ISC10));
		TCNT2=0;
		TCCR2B|= (1<<CS22) ;	// Liga o timer2
		f_t=1;
	}
}

void USARTWriteChar(char buffer)
{
	//Wait until the transmitter is ready
	while((UCSR0A & (1<<UDRE0))==0);			// Bloqueado até o transmissor (UDR0) estar preparado
	UDR0=buffer;
}

void send_msg(char *buffer){
	unsigned char j=0;
	while(buffer[j]!='\0')						// Verifica o fim da string
	{
		while (( UCSR0A & (1<<UDRE0)) == 0){}	// Verifica se o buffer de transmissão está vazio (Espera UDRE0 ir a 1)
		UDR0=buffer[j];							// Coloca 1 byte no registo de transmissão
		j++;
	}
}

unsigned char USART_ReceivePolling(){
	char DataByte;
	while (( UCSR0A & (1<<RXC0)) == 0) {}; // Do nothing until data have been received
	DataByte = UDR0 ;
	return DataByte;
}

ISR(USART_RX_vect){			// Enviar a informação apenas quando alterada
	data=UDR0;
	//USARTWriteChar(data);
	if (data=='A')
	aut=OFF;				// Controlado
	else if (data=='B')
	aut=ON;			// Automático
	if (aut==OFF)
	{
		switch (data)
		{
			case 'F':
				dir=1;
				break;
			case 'T':
				dir=2;
				break;
			case 'D':
				dir=3;
				break;
			case 'E':
				dir=4;
				break;
			case 'C':	// Frente-direita
				dir=5;
				break;
			case 'G':	// Frente-esquerda
				dir=6;
				break;
			case 'H':	// Trás-direita
				dir=7;
				break;
			case 'I':	// Trás-esquerda
				dir=8;
				break;
			case 'S':	// STOP
				dir=0;
				break;
		}
	}
	if (data=='W'){		// Reset array
		reset_velo=1;
		velo[0]='0';
		velo[1]='0';
		velo[2]=' ';
		velo[3]=' ';
		k=0;
		}else if (data=='Y'){					// Converte para velocidade
		reset_velo=0;
		//k=0;
		velo[0]='0';							// Eliminar o 'W'
		vel_aux=atoi(velo);						// Converter vetor (string que pode conter numeros) para um inteiro
		if (vel_aux==0) USARTWriteChar('R');	// ERRO
		if (vel_aux>0 && vel_aux<128){			// 128 = 6V (Para alimetação de 12 V) 104 = 6 V (Para alimetação de 14.8 V)
			vel=vel_aux;
		}else vel=127;							// Ligeiramente abaixo de 6 V
		for (int t=1; t<=k; t++){
			USARTWriteChar(velo[t]);			// Imprimir velocidade
		}
		//USARTWriteChar(velo[1]);
		//USARTWriteChar(velo[2]);
		//USARTWriteChar(velo[3]);
	}
	if (reset_velo==1){	//Já está resetado o array da velocidade e vai escrever na posição correspondente o recebido em data
		velo[k]=data;	//velo[0]='W'
		k++;
	}
}

void motores()  // PB1 PB2 PB3 PB4
{
	switch (dir)
	{
		case 1:
			frente();
			break;
		case 2:
			tras();
			break;
		case 3:
			direita();
			break;
		case 4:
			esquerda();
			break;
		case 5:
			frentedireita();
			break;
		case 6:
			frenteesquerda();
			break;
		case 7:
			trasdireita();
			break;
		case 8:
			trasesquerda();
			break;
		case 0:
			stop();
			break;
	}
}

void frente(){
	PORTB &= ~(1<<PINB5) & ~(1<<PINB2) & ~(1<<PINB4);
	PORTD &= ~(1<<PIND7);
	//PORTB &= ~(1<<PINB5); // FRENTE
	//PORTD &= ~(1<<PIND7);
	PORTB |= (1<<PINB2) | (1<<PINB4);
	OCR0A = vel;
	OCR0B = vel;
}
void tras(){
	PORTB &= ~(1<<PINB5) & ~(1<<PINB2) & ~(1<<PINB4);
	PORTD &= ~(1<<PIND7);
	//PORTB &= ~(1<<PINB2) & ~(1<<PINB4);	// TRÁS
	PORTB |=  (1<<PINB5);
	PORTD |= (1<<PIND7);
	OCR0A = vel;
	OCR0B = vel;
}
void direita(){
	PORTB &= ~(1<<PINB5) & ~(1<<PINB2) & ~(1<<PINB4);
	PORTD &= ~(1<<PIND7);
	//PORTB &= ~(1<<PINB5) & ~(1<<PINB4); // DIREITA
	PORTD |= (1<<PIND7);
	PORTB |= (1<<PINB2);
	OCR0A = vel+velesq;
	OCR0B = vel;
}
void esquerda(){
	PORTB &= ~(1<<PINB5) & ~(1<<PINB2) & ~(1<<PINB4);
	PORTD &= ~(1<<PIND7);
	//PORTB &= ~(1<<PINB2) // ESQUERDA
	//PORTD &= ~(1<<PIND7);
	PORTB |= (1<<PINB5) | (1<<PINB4);
	OCR0A = vel+velesq;
	OCR0B = vel;
}
void frentedireita(){
	PORTB &= ~(1<<PINB5) & ~(1<<PINB2) & ~(1<<PINB4);
	PORTD &= ~(1<<PIND7);
	//PORTB &= ~(1<<PINB5); // FRENTE DIREITA
	//PORTD &= ~(1<<PIND7);
	PORTB |= (1<<PINB2) | (1<<PINB4);
	OCR0A = vel+pwm(3);
	OCR0B = vel;
}	
void frenteesquerda(){
	PORTB &= ~(1<<PINB5) & ~(1<<PINB2) & ~(1<<PINB4);
	PORTD &= ~(1<<PIND7);
	//PORTB &= ~(1<<PINB5); // FRENTE ESQUERDA
	//PORTD &= ~(1<<PIND7);
	PORTB |= (1<<PINB2) | (1<<PINB4);
	OCR0A = vel;
	OCR0B = vel+pwm(3);
}
void trasdireita(){
	PORTB &= ~(1<<PINB5) & ~(1<<PINB2) & ~(1<<PINB4);
	PORTD &= ~(1<<PIND7);
	//PORTB &= ~(1<<PINB2) & ~(1<<PINB4);	// TRÁS DIREITA
	PORTB |=  (1<<PINB5);
	PORTD |= (1<<PIND7);
	OCR0A = vel+pwm(3)+velesq;
	OCR0B = vel;
}
void trasesquerda(){
	PORTB &= ~(1<<PINB5) & ~(1<<PINB2) & ~(1<<PINB4);
	PORTD &= ~(1<<PIND7);
	//PORTB &= ~(1<<PINB2) & ~(1<<PINB4);	// TRÁS ESQUERDA
	PORTB |=  (1<<PINB5);
	PORTD |= (1<<PIND7);
	OCR0A = vel;
	OCR0B = vel+pwm(3);

}
void stop(){
	PORTB &= ~(1<<PINB5) & ~(1<<PINB2) & ~(1<<PINB3) & ~(1<<PINB4); // PARADO
	OCR0A = 0;
	OCR0B = 0;
}

void triggersonar(){
	//for (int d = 0; d < 5; ++d)
	//{
	PORTD |= (1<<PD4);					// Ativa trigger
	cont_10us=0;						// Cada definição a zero gasta 2 ciclos de clock = 2us
	cont_10us=0;
	cont_10us=0;
	tempo=0;							// Inicializar variaveis temporais
	tempfim=0;
	tempinit=0;
	PORTD &= (~(1<<PD4));				// Desativa trigger
	flag=1;
	while(flag!=0){};					// Obtive valor novo de dist
	if ((dist<1) || (dist>400)) dist = 400;	// Limite lógico definido para o sonar
	//EICRA|= (1<<ISC01) | (1<<ISC00);	// Subida do sinal gera interrupção (INT0)
	//COUNTA[d]=dist_m;
	//}
	//dist = moda(COUNTA,5);
}

void scan_e(){				// Ativar trigger sonar traseiro esquerda
	PORTC |= (1<<PC0);
	cont_10us=0;						// Cada definição a zero gasta 2 ciclos de clock = 2us
	cont_10us=0;
	cont_10us=0;
	cont_10us=0;						// Inicializar variaveis temporais para garantir pelo menos 10 us
	cont_10us=0;
	cont_10us=0;
	PORTC &= (~(1<<PC0));				// Desativa trigger
	while(flag_t==0){};
	//EICRA|= (1<<ISC11) | (1<<ISC10);	// Subida do sinal gera interrupção (INT1)
	flag_t=0;
	f_t=0;
	dist_e=(pulse*64)/58;
}
void scan_d(){
	int pulsa=0;
	PORTC &= ~(1<<PORTC1);				// Desligar PORTC1
	cont_10us=0;
	TCNT2=0;
	PORTC |= (1<<PORTC1);				// Ligar PORTC1
	cont_10us=0;						// Cada definição a zero gasta 2 ciclos de clock = 2us
	cont_10us=0;
	cont_10us=0;
	cont_10us=0;						// Inicializar variaveis temporais para garantir pelo menos 10 us
	cont_10us=0;
	cont_10us=0;
	PORTC &= ~(1<<PORTC1);				// Desligar PORTC1
	while( !(PINC & (1 << PINC2)) );	// Espera que PINC2 tome o valor 1
	TCCR2B|= (1<<CS22);                 //LIGAR TIMER
	while( PINC & (1 << PINC2) );		// Espera que PINC2 tome o valor 0
	TCCR2B = 0;			                //PARAR TIMER
	pulsa=TCNT2;						//COPIAR REGISTO DO TIMER
	dist_d=((pulsa*70)/58)-46;           //Conversão tempo em distância
	if (dist_d<=0) dist_d=1;
	TCNT2=0;                            // Reiniciar TIMER2 a 0
}

/*
int moda(int a[],int n) {
	int  maxCount = 0;
	float maxValue = 0;
	for (int k = 0; k < n; ++k) {
		int count = 0; 
		for (int j = 0; j < n; ++j) {
			if ( ( a[j] > (0.95*a[k]) ) && ( a[j] < (1.05*a[k]) ) )
			++count;
		}
		if (count > maxCount) {
			maxCount = count;
			maxValue = a[k];
		}
	}
	return maxValue;
}		
*/
void teste_traseiro()
{
	char buff[20];
	if (flag_tras==0){				//flag_tras = 1 já detetou um obstáculo atrás
		scan_e();
		//itoa(dist_e,msg, 10);			// Converte de inteiro para string, 10 significa decimal (2 - binario e 16 - hexadecimal)
		//sprintf(buff, "E=%s, ",msg);
		//send_msg(buff);
		if( dist_e < dist_mint)
		{
			//USARTWriteChar('E');
			//USARTWriteChar('E');
			//_delay_ms(1000);
			stop();
			flag_tras=1;
		}else{
			tras();
			_delay_ms(250);
			//_delay_ms(500);
		}	
	}
	if (flag_tras==0){				//flag_tras = 1 já detetou um obstáculo atrás
		scan_d();
		//itoa(dist_d,msg, 10);			// Converte de inteiro para string, 10 significa decimal (2 - binario e 16 - hexadecimal)
		//sprintf(buff, "D=%s, ",msg);
		//send_msg(buff);
		if( dist_d < dist_mint)
		{
			stop();
			//USARTWriteChar('D');
			//USARTWriteChar('D');
			//_delay_ms(1000);
			flag_tras=1;
			}else{
			tras();
			_delay_ms(250);
			//_delay_ms(500);
		}
	}
}

void send_dist(){
	itoa(dist,msg, 10);				// Converte de inteiro para string 10 significa decimal (2 - binario e 16 - hexadecimal)
	sprintf(msg, "%s , ",msg);
	send_msg(msg);
}

int main(void)
{
	char buff[20],i=0, f_s=0;
	int dist_dir = 0, dist_esq = 0, servo=1850;
	init();
	sprintf(msg, "\nAGV READY...... \n");
	send_msg(msg);
	/*sprintf(msg, "*RR252G111B3");
	send_msg(msg);
	sprintf(msg, "*LR252G111B3");
	send_msg(msg);*/
	OCR1A=1850;
	//while(1){
		/*scan_e();
		itoa(dist_e,msg, 10);			// Converte de inteiro para string, 10 significa decimal (2 - binario e 16 - hexadecimal)
		sprintf(buff, "E=%s, ",msg);
		send_msg(buff);
		_delay_ms(200);
		scan_d();
		itoa(dist_d,msg, 10);			// Converte de inteiro para string, 10 significa decimal (2 - binario e 16 - hexadecimal)
		sprintf(buff, "D=%s, ",msg);
		send_msg(buff);
		_delay_ms(400);*/
		/*teste_traseiro();
		flag_tras=0;
		triggersonar();
		_delay_ms(250);
		itoa(dist,msg, 10);			// Converte de inteiro para string, 10 significa decimal (2 - binario e 16 - hexadecimal)
		sprintf(buff, "F=%s, ",msg);
		send_msg(buff);
	}*/
	while (1) {	
		if (aut==ON){					// AUTOMÁTICO
			if ((flag==0)&&(f_avirar==0)){				// Acabou uma leitura do sonar e o AGV não está a virar
				if (direcao == 0){		// Em frente	
					i++;
					if(i==4){			// Roda o servo constantemente (ao fim de 50 ciclos) para a seguinte posição
						i=0;
						f_s=1;			// Flag que indica que servo vai rodar
						if(OCR1A==2100){
							OCR1A=1850;
						}else if(OCR1A==1850){
							if (flag_servo==0){
								flag_servo=1;
								OCR1A=1600;
							}else{
								flag_servo=0;
								OCR1A=2100;
							} 
						}else{
							OCR1A=1850;
						}
					}
					frente();
					if (f_s==1){		// Delay mecanico da rotação do servo necessário
						_delay_ms(250);
						f_s=0;
					}
					//triggersonar();
					triggersonar();
					send_dist();
					//if ((dist>=2) && (dist<40)){
						//triggersonar();
						if ((dist>=2) && (dist<=dist_minf)){
							stop();
							sprintf(buff, "STOP\n",msg);
							send_msg(buff);
							//USARTWriteChar('S');
							direcao=1;
							flag_tras=0;		// Inicializa a flag para permitir leitura atrás
							teste_traseiro();
							teste_traseiro();	
							flag_tras=0;		// Inicializa a flag para permitir leitura atrás
							//USARTWriteChar('B');
							//tras();		
							//_delay_ms(1000);	// Tempo de deslocamento para trás
							servo=OCR1A;		// Guarda posição do servo para ser processada
							stop();
						}
					//}
				}else if (direcao == 1){
					OCR1A = 2800;				// Sonar esquerda
					_delay_ms(600);				// Delay mecânico
					//triggersonar();
					triggersonar();
					itoa(dist,msg, 10);			// Converte de inteiro para string, 10 significa decimal (2 - binario e 16 - hexadecimal)
					sprintf(buff, "ESQ=%s, ",msg);
					send_msg(buff);
					dist_esq = dist;
					/*if ((dist<1) || (dist>400)){
						dist_esq = 400;
					}else{ 
						dist_esq = dist;
					}*/
					direcao=2;					
				}else if (direcao == 2){	
					OCR1A = 800;				// Sonar direita
					_delay_ms(600);				// Delay mecânico
					//triggersonar();
					triggersonar();
					itoa(dist,msg, 10);			// Converte de inteiro para string, 10 significa decimal (2 - binario e 16 - hexadecimal)
					sprintf(buff, "DIR=%s, ",msg);
					send_msg(buff);
					dist_dir = dist;
					/*if ((dist<1) || (dist>400)){	
						dist_dir = 400;
						}else{
						dist_dir = dist;
					}*/
					f_avirar=1;					// O AGV vai começar a virar
					direcao = 0;
					OCR1A = servo;				// Servo continua na posição antes do sonar detetar um objeto
					_delay_ms(400);				// Delay mecanico
					if (dist_dir >= dist_esq){
						direita();
						//USARTWriteChar('D');
					}else {
						esquerda();
						//USARTWriteChar('E');
					} 
					//_delay_ms(500);
				}
			}else if ((flag==0)&&(f_avirar==1)){	// Acabou uma leitura do sonar e o AGV está a virar. Este if é responsável por detetar a posição que o AGV vai tomar quando detetar um obstáculo
				if (servo!=1850){					// Se posição do servo quando detetou o obstáculo for diferente do centro
						servo=1850;					
						OCR1A=1850;					// Coloca lo no centro para ler valores "frontais" do AGV
						//_delay_ms(2000);					
						//USARTWriteChar('A');
				}else{
					triggersonar();					// Se posição do servo quando detetou o obstáculo for a do centro faz as leituras necessárias até encontrar a posição que respeite a próxima condição
					if (dist>=120){
						f_avirar=0;					// O AGV detetou melhor caminho
						stop();						// O AGV para de virar
						//USARTWriteChar('B');
						//_delay_ms(2000);
						//_delay_ms(100);			 			
					}
				}
			}
			
		}else{			// CONTROLO REMOTO
			motores();	
		}
	}
}		

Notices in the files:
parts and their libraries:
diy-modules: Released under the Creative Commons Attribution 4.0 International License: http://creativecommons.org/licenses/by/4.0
